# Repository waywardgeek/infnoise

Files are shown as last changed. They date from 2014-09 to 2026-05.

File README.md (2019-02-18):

### Infinite Noise TRNG (True Random Number Generator)

For instructions for compiling the and using Infinite Noise TRNG driver, go to the software
sub-directory, and read the [README](software/README.md) file there.  Both Linux and Windows
are supported.

The Infinite Noise TRNG is a USB key hardware true random number generator.  It uses what
I call a "Modular Entropy Multiplier" architecture (previously Infinite Noise Multiplier or
FireBug).  Besides being simple, low-cost, and fast, it is much easier to get right than
other TRNGs.  It naturally defends against influence from outside signals, such as radio
interference and power supply noise, making it simple to build securely, without requiring
an expert in analog design.  Modular entropy multipliers produce a provable and easily
measured level of entropy based on thermal noise, approximately equal to log2(K) per
output bit, where K is a gain between 1 and 2 set by two resistors around an op-amp.  A
"health monitor" can track this and verify that the output entropy is within the expected
range, which for the Infinite Noise TRNG described below is within 2% of log2(1.82).

Modular entropy multipliers are suitable for both board level implementation and ASIC
implementation.  Speed is limited by the speed of a gain stage and a comparator, and can
run in excess of 100 Mbit/second per second with high performance components.  Cheap
solutions with CMOS quad op-amps can run at 8Mbit/second.

Adjacent bits from a modular entropy multiplier are correlated, so whitening is required
before use in cryptography.  This should be done by continually reseeding a
cryptographically secure hash function such as SHA-512, Blake2b, Keccak-1600 (SHA3), or a
stream cipher such as ChaCha.  This implementation uses Keccak-1600 with cryptographically
secure reseeding of more than 400 bits of entropy at a time, overcoming a trickle in/out
problem present in the GNU/Linux /dev/random system.  Users who need many megabytes per second
of data for use in cryptography can set the outputMultiplier as high as they like, which
causes Keccak to generate outputMultiplier\*256 bits per reseeding by the Infinite Noise
TRNG.

The modular entropy multiplier architecture was invented by Peter Allan in 1999, which he
called [Firebug](http://apa.hopto.org/firebug).  I reinvented it in 2013.  As usual, most
of my good ideas are rediscoveries of existing ideas :-)  Peter has his own
version called [the Redoubler](https://github.com/alwynallan/redoubler), which
is awesome.  It really is the _right_ way to generate random bits, whether on a
board with standard parts, or on an custom chip.

### Crowd Supply campaign

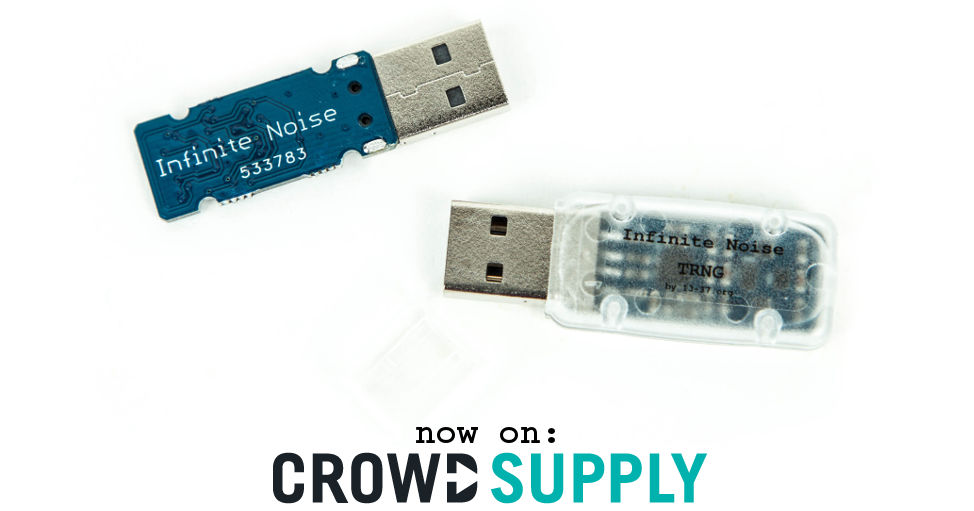
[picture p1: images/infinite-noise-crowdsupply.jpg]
Infinite Noise Crowd Supply campaign Infinite Noise Crowdsupply campaign.


With the aid of crowdfunding, the Infinite Noise will soon be produced (again)! The campaign is driven by Manuel Domke, founder of a fresh electronics manufacturing company called 13-37.org electronics. 

[Check the Crowd Supply project page for latest updates](https://www.crowdsupply.com/13-37/infinite-noise-trng)

### The Eagle open-source boards work!

Here is the first completed Infinite Noise USB key.  I offered this model on
Tindie to help get the modular entropy multiplier concept out there initially.

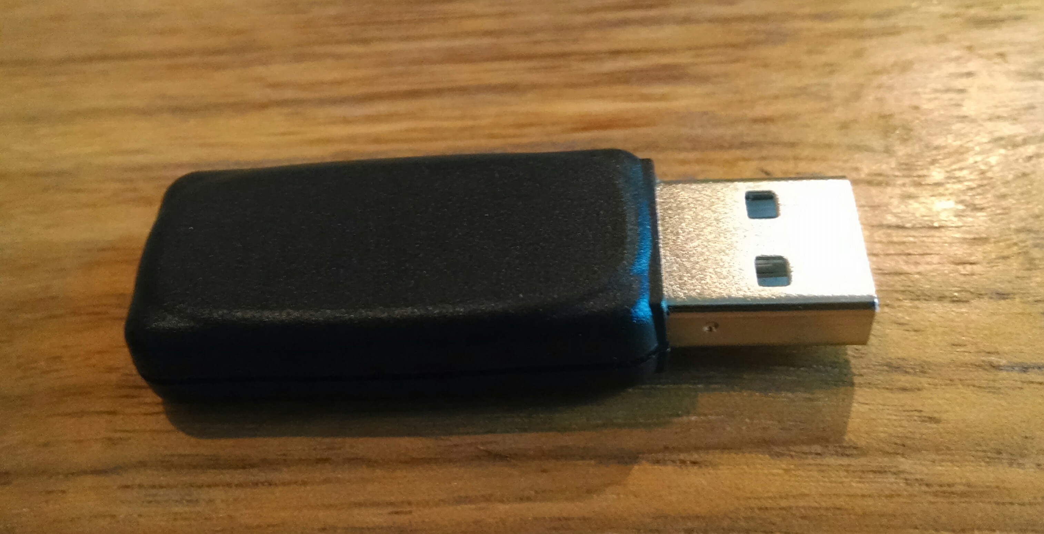
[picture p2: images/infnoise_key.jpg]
Picture of Infinite Noise USB key Infinite Noise USB key


Here are the first three boards from OSH Park.  They work _exactly_ as predicted.  They all
generate 300,000 bits per second, resulting in a measured 259,000 bits of entropy per second, which is within 0.5% of the predicted value of log2(1.82).

All three boards should produce log2(1.82) = 0.864 bits of entropy per bit by design.  The first one is estimated
to produce 0.867, while the second one produces 0.868, and the third is 0.867.

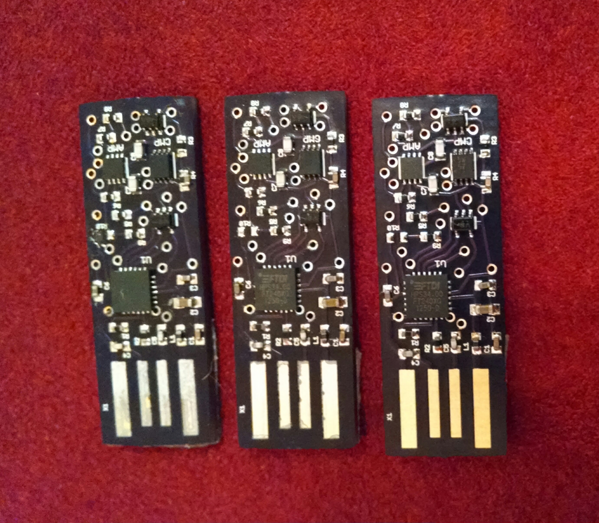
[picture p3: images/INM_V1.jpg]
Picture of Infinite Noise Multiplier circuit board Infinite Noise Multiplier


Here is the latest schematic:

![Schematic of Infinite Noise Multiplier](images/infnoise.png?raw=true "Infinite
Noise Multiplier")

Here is the latest board layout (thanks, EagleWorks!):

![Board layout of Infinite Noise Multiplier](images/infnoise_brd.png?raw=true "Infinite
Noise Multiplier")

The breadboard worked, too.  Estimated entropy per bit is 0.81 for the bread-board.  By design, it should
be 0.80, so it is very close to the prediction.  The breadboard proved out much of the theory of operation, as well os providing raw data for entropy testing.

![Breadboard of Infinite Noise Multiplier](images/infnoise_breadboard.jpg?raw=true "Infinite
Noise Multiplier")

Here is the voltage on one of the hold cap:

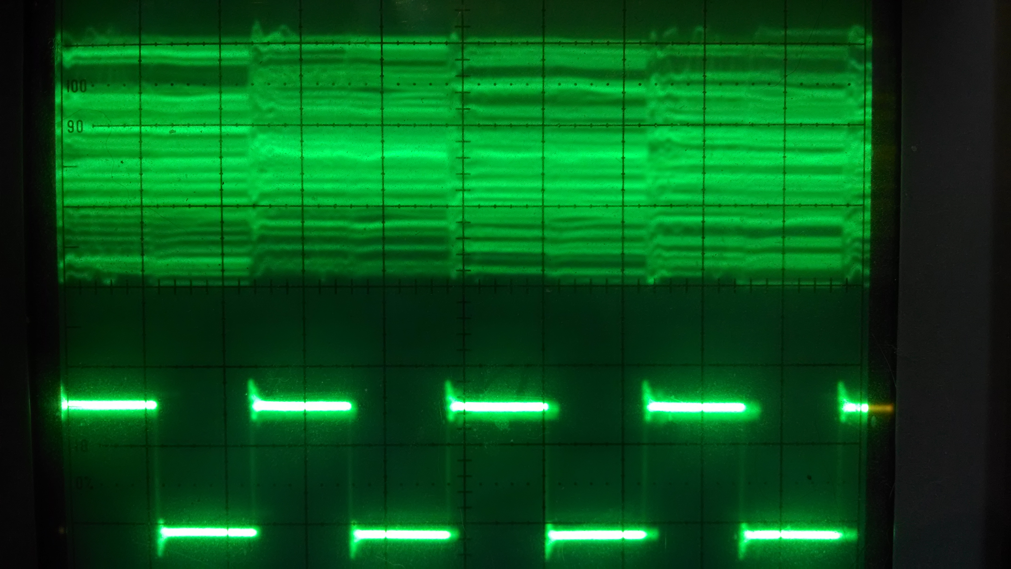
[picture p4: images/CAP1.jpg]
Traces on left hold cap


To build one of these for yourself, you can [order three boards from OSH Park for only
$3.25](https://oshpark.com/profiles/WaywardGeek), and then buy parts from [Digikey and
Mouser as described in the
BOM](https://github.com/waywardgeek/infnoise/blob/master/eagle/BOM.xlsx?raw=true).  I
designed this board to be cheap, not easy to assemble by hand.  I use 2 QFN parts and
three with 0.5mm lead pitch.  If you want to [build these yourself the way I
do](https://www.sparkfun.com/tutorials/59), consider uploading the [infnoise.brd
file](https://raw.githubusercontent.com/waywardgeek/infnoise/master/eagle/infnoise.brd) to
[OSH Stencils](https://www.oshstencils.com/) and ordering a solder paste stencil for $7.
I get the [solder paste from SparkFun](https://www.sparkfun.com/products/12878).  Kudos to
OSH Park, OSH Stencil, SmallBatchAssembly, and DigiSpark!  They're making this whole party
possible!

The total for all the parts, including boards from OSH Park, come to $5.69 each, in 1,000
unit quantities.  However, that cost is dominated by USB related parts, particularly the
FT240X chip, the USB connector, and the USB-stick enclosure.  Just the components for the
modular entropy multiplier come out to $0.97.

Cor van Wandelen was kind enough to create these scatter plots showing the non-randomness
in the raw output.
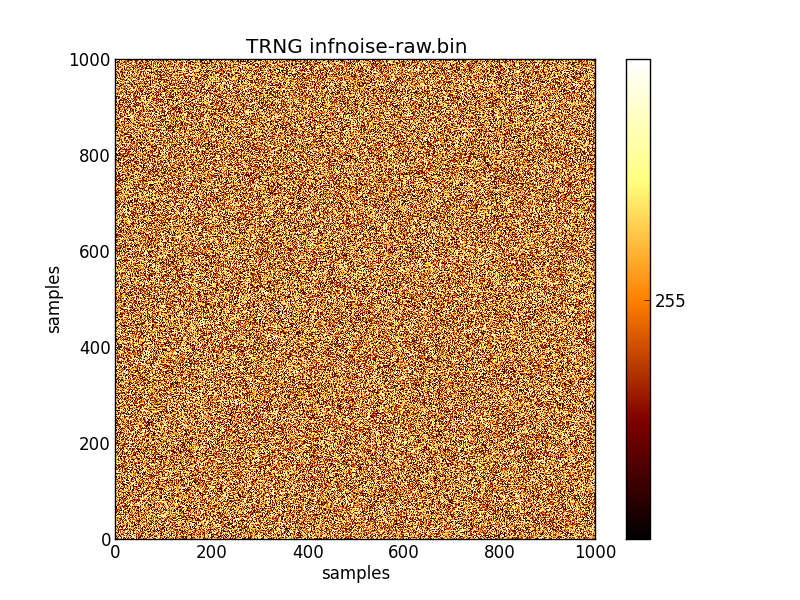
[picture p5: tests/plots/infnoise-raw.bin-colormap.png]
color plot of raw data Color plot

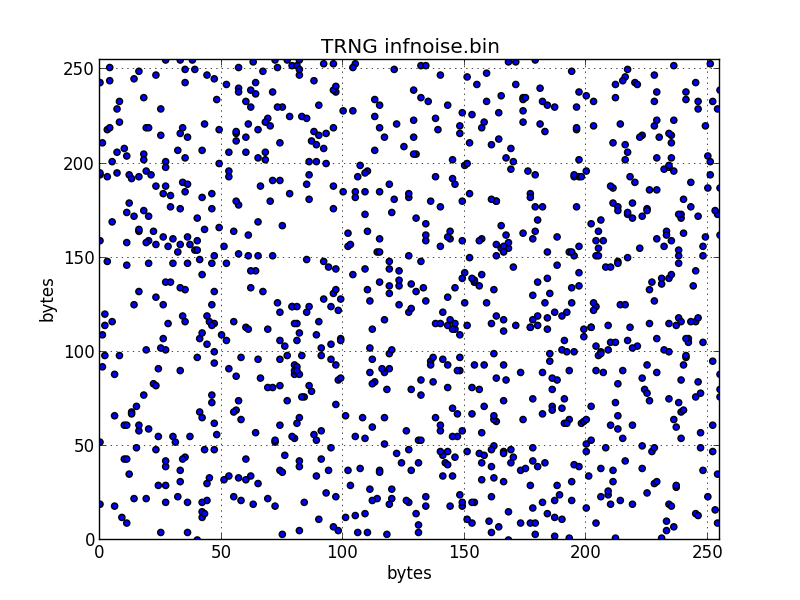
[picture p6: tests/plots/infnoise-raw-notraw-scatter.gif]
scatter plot of raw data Scatter plot


Here is a faster version that uses a more expensive op-amp from TI:

![Schematic of Infinite Noise Multiplier](infnoise_small/schematic.png?raw=true "Infinite
Noise Multiplier")

### The Problem: Noise Sensitivity, and Signal Injection

True random number generators are very difficult to get right.  Generally, they amplify a
tiny noise signal, perhaps only a microvolt in amplitude, by a factor of millions or
billions, until the signal is an unpredictable digital signal.  This signal is then
sampled to see if it's a 0 or 1.

The problem with this approach is the weak noise source can easily be influenced by other
nearby signals, which may be under the control of an attacker, or perhaps observable by an
attacker, enabling him to predict the output.  Systems built with massive amplification of tiny noise sources often require power supply filters and EMI shielding, and even then remain difficult to prove secure.  Generally, an expert analog designer is needed to get it right.

Intel's RDRAND instruction is a perfect example.  It uses rapid amplification of thermal
noise to determine the power-up state of a latch.  Unfortunately, this source of entropy
is highly power-supply and cross-talk sensitive.  Intel claims to have
carefully shielded their thermal noise source, but without a thorough pubic audit of both
the design and layout, including all potential sources of interference, it is not possible
to trust the RDRAND instruction as the source of entropy for cryptography.

With such strong sensitivity, these TRNG architectures are potential targets for signal
injection by an attacker, who can cause the TRNG to generate his desired output rather
than true random data.

### The Solution: Modular Multiplication

Unpredictable noise sources are tiny, and must be massively amplified to be used by an
TRNG.  Other TRNG architectures amplify these signals until they saturate, becoming
digital 1's and 0's.  They rely on careful design and shielding to keep outside signals
from influencing the noise source.

For example, if we amplify a tiny noise source by 1 billion in a system that saturates at
3.3V, then 1uV of noise will be amplified causing the output to be about 3.3V.  An
attacker need only introduce at least -1uV to cause the TRNG to saturate at 0V instead.
An attacker with even this tiny influence can entirely control the output.

If TRNGs used modular multiplication to amplify their noise source, this noise sensitivity
problem would go away.

If we multiply a 1uV peak by 1 billion modulo 3.3V, then the result will be about 0.3V,
which will result in a digital 0.  If an attacker subtracts 1uV, causing our noise source
to be at 0.0V, then after amplification, the output is 0V, which still results in a 0.  In
fact, without knowing the current amplitude of the noise source, there is no signal an
attacker can add to our noise source to control the output.  He may be able to flip the
output bit, but since it was already random, his signal injection fails to control the
result, which is still random.  In fact, an attacker's injected signal causes the output
to be _more_ random, since an attacker is a nice unpredictable source of entropy!
Infinite Noise Multipliers _add_ entropy from all noise sources, even those from an
attacker.

### Variations

There are currently 3 versions of Infinite Noise Multipliers documented here.  The
infnoise_small directory describes a low part-count design that works well with op-amps
which have rail-to-rail inputs and outputs.  It runs at 4MHz, outputting 0.86 bits worth of
entropy on each clock (loop gain = 1.82), for a total of over 3.4 Mbit of entropy produced
per second.  The infnoise_fast directory contains a 50% faster design that uses a few more
resistors and an additional op-amp.  This design is suitable for use with a wide range of
op-amps.  It runs at 6MHz, outputting 0.86 bits worth of entropy on each clock (loop gain =
1.82), for over 5Mbit of entropy per second.

Because Infinite Noise Mulitpliers are switched-capacitor circuits, it is important to use
components with low leakage, like the OPA4354 CMOS quad op-amp from TI.  Op-amps with
below 1nA of input bias current will enable running at lower frequencies with less power.

To reproduce these simulations, download the TINA spice simulator from Ti.com.

Here is a "small" modular entropy multiplier:

![Schematic of small Infinite Noise Multiplier](infnoise_small/schematic.png?raw=true "Small
Infinite Noise Multiplier")

Note that the upper left op-amp is used as a comparator, and must settle to either 0V or
Vsup before the lower left op-amp can multiply the input by 2X.

Here's a "fast" version that does two multiplications in parallel and uses the comparator
result to select the right one.

![Schematic of fast Infinite Noise Multiplier](infnoise_fast/schematic.png?raw=true "Small
Infinite Noise Multiplier")

There is also a [CMOS version described here](http://waywardgeek.net/RNG).

### Simulations

LTspice was used to simulate the small and fast variations.  Here are simulation waveforms
for the small version:

![Simulation of small Infinite Noise Multiplier](infnoise_small/shortsim.png?raw=true "Small
Infinite Noise Multiplier")
![Simulation of small Infinite Noise Multiplier](infnoise_small/longsim.png?raw=true "Small
Infinite Noise Multiplier")

And again for the fast version.

![Simulation of fast Infinite Noise Multiplier](infnoise_fast/shortsim.png?raw=true "Fast
Infinite Noise Multiplier")
![Simulation of fast Infinite Noise Multiplier](infnoise_fast/longsim.png?raw=true "Fast
Infinite Noise Multiplier")

### Theory of Operation

Consider how a successive-approximation A/D converter works.  Each clock cycle, we compare
the input voltage to the output of a D/A converter, and if it's higher, the next bit out
is 1, and if lower, it's a 0.  We use binary search to zero-in on the analog input value.
Here is a block diagram from Wikipedia:

![Successive approximation A/D block diagram](images/SA_ADC_block_diagram.png?raw=true "SAR
A/D Block Diagram")

There is another way to build a successive-approximation A/D that eliminates the D/A
converter.  Compare the input to Vref (1/2 supply), and if it is larger, subtract Vref
from the input.  Then multiply by 2X.  The bit out is the value of the comparator.

    Vin' = Vin >= Vref? Vin - Vref : Vin

This eliminates the D/A converter, and has no limit on how many bits we shift out.  In
reality, the only reason we do not use this architecture for real A/D converters is that
it's accuracy depends on the accuracy of the multiply by 2X operation.  A simple circuit
with 1% resistors would only achieve about a 7 bit resolution.

However, just because the bits are not accurate does not mean we can't keep shifting them
out.  What are we measuring after shifting 30 times?  It's just noise in the circuit, with
no correlation to the original Vin.  It's totally random unpredictable nonsense.  This is
the idea behind the Infinite Noise Multiplier.

If this A/D converter was perfect, both 0's and 1's should shift out with equal
probability, with no correlation between bits.  This has been verified C simulations and
dieharder.  However, due to accuracy limitations on real components, we cannot multiply by
exactly 2X every cycle.  When the loop amplification is < 2X, the entropy per output bit
is reduced, but can be easily computed.  If E is the entropy per bit, and K is the loop
amplification, then:

    E = log(K)/log(2)

or equivalently:

    E = log2(K)

This provides a simple way to calculate the entropy added to an entropy pool per bit.
The program infnoise.c directly measures the entropy of modular entropy multiplier output,
and compares this to the estimated value.  Both simulations and actual hardware show that
they correlate well.

The "fast" board level version uses two op-amps and comparator to impliment a modular
multiplication using a couple of tricks.  First, multiplication by 2 modulo Vsup is
accomplished by multiplying relative to either GND or Vsup.  When multiplying relative to
GND, a 0.2V signal becomes 0.4V.  When multiplying relative to a 3V Vsup, a 2.8V signal
becomes 2.6V, because 2.8V is 0.2V below 3V, and after 2X, it's 0.4V below 3V.  The math
comes out the same as if I'd multiplied relative to GND, and simply subtracted Vsup if the
result was > Vsup:

    Vsup - 2*(Vsup - Vin) = Vsup - 2*Vsup + 2*Vin = 2*Vin - Vsup
        = 2*Vin mod Vsup

So, we multiply by 2 either way, and only subtract out Vsup if needed.  This is identical
to multiplication modulo Vsup.  The comparator simply selects the output of one of the two
op-amps.  This is the basic analog modular multiplier.

A second trick used to create the "small" version was to notice that the output of the
comparator could be used to combine both multiplier op-amps into 1.  This abuse of the
comparator output needs to be carefully checked.  In particular, the output is generally
treated as a digital signal, but in this case, it is used as an analog singal.  Care
should be taken not to load the OUT signal significantly.

### Provable Entropy, Based on Thermal Noise

The RMS thermal noise generated by a resistor of value R is:

    Vnoise = sqrt(4*Kb*T*deltaF*R)

where Kb is Boltzmann's constant 1.3806504×10-23 J/K, T is temperature in Kelvin (about
293 for room temperature), and deltaF is the frequency range of noise being measured.

For the V1 version of the Infinite Noise boards above, the op-amp has an 8MHz unit gain
crossover, and a low load negative input with 10K Ohms in parallel with 8.2K Ohms, which
is 4.5K Ohms.  Vnoise up to unity crossover is about 24uV, and gets amplified by the
op-amp gain K of 1.82 to about 40uV, and held on a 220pF capacitor.  A 40uV change on the
hold capacitors results in a current of about 55,000 electrons, so the hold capacitors are
able to capture about 15 bits of resolution of this noise signal, which gets amplified by
K and combined with later noise samples in the hold capacitors every cycle.  The
capacitors s hold about 2^31 different charge levels in the range of 0.3V to 3V.  This is
effectively a 31-bit register which we multiply by 1.82 every cycle and add a 15 bit noise
signal.  This results in entropy shifted out just slightly less than log2(1.82), since
this entropy compression does not result in 100% pure entropy (just very close).

changes the output of the comparator several cycles later.  Each cycle, this 15-bit noise
signal is added in, far in excess of the log2(K) of entropy we shift out, enabling us to
concentrate entropy in the hold capacitors, which hold over 2^32 electrons when
discharging from the design range of 3V to 0.3V.  Note that we are not assuming successive
noise samples of this 8MHz noise, when measured at 480KHz, will be completely uncorrelated,
but only that concentrating a 15-bit representation of sequential samples will have a few
bits of "surprise", which is log2(1/probability of guessing the next sample).

### Analysis of Analog Modular Multiplication

Consider a traditional zener TRNG:

    Vzener -> Multiply by 1e9 relative to Vref -> Clamp between -Vsupply and Vsupply -> digital 0/1

For simplicity, assume our amplifier has positive and negative supplies, Vsupply, and
-Vsupply.  If Vzener\*1e9 >= 0, then the output is a digital 1, otherwize 0.

There are variations on this theme, but this is basically how Zener TRNGs work.  The math
computed by this circuit is:

    clamp(-Vsupply, Vsupply, 1e9*Vzener)

where the first two parameters are the lower and upper clamping voltages, and the third
parameter is the amplified signal.

The problem with this design is that an attacker, Malory, can override the tiny zener
noise source with radio-signals, or any of a number of attacks.  Basically, if he can find
a way to add his signal to Vzener, then the circuit does this:

    clamp(-Vsupply, Vsupply, 1e9*(Vzener + Vmallory))

If Vmallory is always just a bit larger than Vzener in magnitude, then Mallory can
completely determine the output, because Mallory can make Vzener + Vmallory greater or
less than zero at will, and after multiplying by 1e9 it the amplifier will saturate in the
direction of the sign of Vmallory.

What if we used modular multiplication instead?  Assume we represent Vzener now as a
positive voltage between 0 and Vsupply so we can use the normal mod operation.  In this
case the normal output would be:

    Vzener*1e9 mod Vsupply -> compare to Vsupply/2 -> 1 if > Vsupply/2, 0 otherwise

This is even _more_ unpredictable than the original version. Only the portion of Vzener
between +/- Vsupply/1e9 made any difference in the output before, but now we use the
entire amplitude of Vzener.  The amplitude of Vzener has additional entropy which now
further whitens the output bit.

When Mallory attacks this system, injecting Vmallory into the same node as Vzener, it
computes:

    (Vzener + Vmallory)*1e9 mod Vsupply = Vzener*1e9 + Vmallory*1e9 mod Vsupply

Let Vz = Vzenner\*1e9 mod Vsupply, and Vm = Vmallory\*1e9 mod Vsupply.  Then the output
is just:

    Vz + Vm mod Vsupply

Vz is unpredictably distributed between 0 and Vsupply, hopefully somewhat uniformly.
How can Mallory determine what to add to it to control the output?  He can not.
His interference can only _increase_ the entropy of the output, since Mallory's attack is
itself an entropy source, further randomizing the result.

### Rolling Up the Loop

A 30-long cascade of switched capacitor 2X modular multipliers is a lot of hardware!
Fortunately, it is possible to reuse the same multiplier for each stage, without even
slowing down the circuit.  In our long chain of 2X modular multipliers, we computed:

    A1(1) = 2*Vzener(0) mod Vsupply
    A2(2) = 2*A1(1) mod Vsupply
    A3(3) = 2*A2(2) mod Vsupply
    ...
    A30(30) = 2*V29(29) mod Vsupply

Here, Vzener(0) is Vzener when sampled at the first clock pulse.  Vzener(n) is the voltage
sampled on the nth clock pulse.  An(i) is the output of the nth 2X modular multiplier at
clock cycle i.  Instead of using 30 stages, what would happen if we simply fed the output
of the 2X modular multiplier stage back on itself?  We'd just have A instead of A1 ..
A30:

    A(1) = 2*Vzener(0) mod Vsupply
    A(2) = 2*(Vzener(1) + A(1) mod Vsupply 
          = 2*Vzener(1) + 4*Vzener(0) mod Vsupply
    A(3) = 2*(Vzener(2) + A(2)) mod Vsupply
          = 2*Vzener(2) + 4*Vzener(1) + 8*Vzener(0) mod Vsupply
    ...
    A(30) = 2*Vzener(29) + 4*Vzener(28) + 8*Vzener(27) + ... + 2^30*Vzener(0) mod
    Vsupply

If 2^30\*Vzener(0) mod Vsupply is an unpredictable value, then the other terms can in no
way reduce this unpredicability.  What if Mallory attacks?  In that case, at step 30, we
have:

    A(30) = 2*(Vzener(29) + Vmallory(29)) + ... + 2^30*(Vzener(0) + Vmallory(0) mod
    Vsupply
            = [2*Vzener(29) + 4*Vzener(28) + ... + 2^30*Vzener(0)] +
              [2*Vmallory(29) + 4Vmallory(28) + ... + 2^30*Vmallory(0)] mod Vsupply

The output is just the signal we had before without Mallory's influence, plus a value
injected by Mallory, mod Vsupply.  Once again if Mallory does not know what the value of
A(30) would have been, he cannot control the result.  He can only make it more random.

The value of A acts as an entropy pool, collecting entropy from all signals that impact
it's value.

### We Don't Need Zener Noise

In reality, there are many sources of unpredictable noise in every circuit.  There's large
predictable and controllable noise, like power supply noise, and tiny 1/f noise in the
multi-gigahertz range.  Shot noise, thermal noise, EMI, cross-talk... you name it, no
matter where we look, there's noise.  Infinite noise multipliers amplify them all in
parallel, and adds them together effectively in an tiny entropy pool.  Zener noise would
be just one more source of noise in a symphony of existing noise sources, and will not
enhance the resulting entropy enough to bother.

A modular entropy multiplier will amplify _every_ source of niose and amplify it until it is
larger than Vsupply.  It adds them together and amplifies them in parallel.  Every device
in the signal path loop contributes. 

With N sources of noise, the output looks like:

    V1(1) = Vnoise1(1) + Vnoise2(1) + Vnoise3(1) ... VoinseN(1)
    ...
    V1(30) = [2*Vnoise1(29) + 4*Vnoise1(28) + ... + 2^30*Vnoise1(0)] +
             [2*Vnoise2(29) + 4*Vnoise2(28) + ... + 2^30*Vnoise2(0)] +
             ...
             [2*VnoiseN(29) + 4VnoiseN(28) + ... + 2^30*VnoiseN(0)] mod Vsupply

Each individual noise sources contributes its own power-of-two sequence to the total.
A micro-volt noise source contributes nearly as strongly as a Vsupply/10 amplitude noise
source.

The mashing together of noise source data with unbounded modular multiplications leads to
awesome entropy levels.  Just how awesome?  Consider just thermal noise from one resistive
summing node (the minus terminal on op-amp in the 2X gain stage).

How correlated are successive samples?  How badly does this impact our output?  It turns
out that high correlation is OK.  What we want is high resolution contribution of noise
samples, even more than low correlation.

Suppose sample Vnoise(0) is 1.034 uV, and Vnoise(1) is 1.019 uV.  That is
some bad correlation, but 14 clock cycles later, the difference in amplitudes between
these samples will have the output toggling unpredictably.  What matters is not
correlation between noise samples, but the accuracy to which we can remember the
difference between them in our circuit.  This should be limited only by electron counts on
our hold capacitor.  It has an integer number of electrons at any time.  About 2.5 billion
electrons flow out of 100pF holding caps when charging from 0.5V to 4.5V.  That's about 31
bits of resolution.  Every time we capture noise on these caps, it adds or subtracts an
integer number of electrons.  Each electron contributes about 1.6nV on our hold cap.  So
long as we can capture noise that has significantly more than 1.6nV of unpredictability,
we should be able to keep the output generating close to 1 bit of entropy per clock.  In
this example, both noise samples had over 10X the minimum resolution in unpredictable
noise, and easily contributed a bit of entropy each to our 31-ish bit entropy pool.

### Whitening the Right Way

Data coming from true random number generators is never 100% random.  I am aware of no
exceptions.  Whitening is required in all cases before the data is suitable for use in
cryptography.

Most TRNGs build whitening into the hardware.  This is a _mistake_, at least if the
whitening cannot be turned off.  Respectable TRNGs, such as [OneRNG](http://onerng.info/)
and [Entropy Key](http://www.entropykey.co.uk/) provide hardware whitening, but also
provide access to the raw data streams for health analysis.

I prefer to follow the KISS rule when it comes to security.  The more complex the TRNG
key, the more likely it is insecure.  Therefore, the initial Infinite Noise Multiplier
does not even have a microcontroller onboard, and only returns raw data, direct from the
noise source.  Whitening is done in the Infinite Noise driver.

The Infinite Noise driver uses the reference version of the SHA3 "sponge", called Keccak,
with a 1600 bit state.  To make the state of the sponge unpredictable, it is initialized
with 20,000 bits of of Infinite Noise data before any data is output.  After that, reading
bytes from the SHA3 sponge blocks until twice as many bytes of entropy have been fed into
the sponge from the Infinite Noise TRNG.

### Non-Power-of-Two Multiplication

The circuit shown in infnoise_fast multiplies by 1.82 every clock rather than 2.0.  As
stated above, this reduces the entropy per output bit to log(1.82)/log(2) = 0.86 bits of
entropy per output bit.

Suppose in cycle 0, the noise Vnoise(0) is +/- Vsupply/2^30V every cycle.  At most 31 clock
cycles can go by before the output toggles due to Vnoise(0), because on cycle 31, it's
contribution will be 2\*Vsupply, and the remaining noise contributions can do no more than
subtract Vsupply.  This will have to be subtracted out.  The cycle x1 where we know
Vnoise(0) will have toggled the output is:

    Vnoise(0)*2^x1 >= 2*Vsupply
    2^x1 >= 2*Vsupply/Vnoise(0)
    x1 >= log(2*Vsupply/Vnoise(0))/log(2)

When multiplying by K, where 1 < K < 2, it takes more clock cycles for Vnoise(0) to reach
Vsupply, insuring that it will have changed the output.  The cycle x2 when this happens
is:

    Vnoise(0)*K^x2 >= 2*Vsupply
    K^x2 >= 2*Vsupply/Vnoise(0)
    x2 >= log(2*Vsupply/Vnoise(0))/log(K)

The ratio of the clocks it takes with amplification 2 vs K is:

    x1/x2 = [log(Vsupply/Vnoise(0))/log(2)] / [log(Vsupply/Vnoise(0))/log(K)]
          = log(K)/log(2)

It takes log(2)/log(K) more cycles to insure the output is different.
the entropy shifted out with exactly 2X amplification will be 1 bit per clock.

### Health Monitoring

Infinite Noise Multipliers output entropy at a predictable rate, which is measured
continually.  If the entropy per bit deviates from the theoretical value of log(K)/log(2)
by more than 2% during the previous 80,000 bits, then the driver stops generating output.
Some deviation is expected, since K is dependent on two resistor values, which can be off
by 1% each.  Also, a significant amplitude noise in the system, as well as "misfires", can
cause more entropy to be output than predicted.  The estimated entropy per bit are
continually estimated and compared to expected values.

Entropy per bit is measured as the log2 of one over the probability of seeing a specific
output sequence from the modular entropy multiplier.  The probability of any given output
bit is estimated by keeping a history of results, given the previous 7 bits.  Simulations
with K=1.82 show that using 16 bits rather than 7 gives only a 0.16% improvement in
prediction accuracy, so only 7 are used.

### Entropy Testing

A common program used to estimate entropy in a data stream is "ent".  A sample data file
was created this way (using one of the original V1 boards):

    $ sudo ./infnoise-v1 --raw --debug > foo
    ...
    Generated 14680064 bits.  OK to use data.  Estimated entropy per bit: 0.866710, estimated
    K: 1.823500
    num1s:49.888504%, even misfires:0.159748%, odd misfires:0.127300%
    Generated 15728640 bits.  OK to use data.  Estimated entropy per bit: 0.866856, estimated
    K: 1.823684
    num1s:49.901504%, even misfires:0.145973%, odd misfires:0.160365%
    Generated 16777216 bits.  OK to use data.  Estimated entropy per bit: 0.867010, estimated
    K: 1.823879
    num1s:49.963040%, even misfires:0.146815%, odd misfires:0.145067%

Here's ent's results on the raw data stream this run produced:

    $ ent foo
    Entropy = 7.318058 bits per byte.
    
    Optimum compression would reduce the size
    of this 2072576 byte file by 8 percent.
    
    Chi square distribution for 2072576 samples is 1510131.51, and randomly
    would exceed this value 0.01 percent of the times.
    
    Arithmetic mean value of data bytes is 127.5088 (127.5 = random).
    Monte Carlo value for Pi is 3.427100794 (error 9.09 percent).
    Serial correlation coefficient is -0.005035 (totally uncorrelated = 0.0).

The health monitor does a much better job at estimating the entropy than ent.  The actual
non-randomness is 60% higher than ent predicted.  Ent said 0.915 bits of entropy per bit,
while the health monitor measured 0.867.  The health monitor's entropy estimator is just a
tiny fraction of a percent higher than the model predicts, while ent is off by 4.8% .  The
design target for entropy per bit was log2(1.82) = log(1.82)/log(2) = 0.864.  This is set
by two resistors.  Based on entropy measured by the health monitor, it could compress this
file by 13.3%.

The entropy estimator is based on the model that:

- The device is not rapidly changing the sort of numbers it puts out, so history can be
  used as a guide.
- There is no special state stored in the modular entropy multiplier that could cause data
  to be different each clock cycle, other than on even/odd cycles.
- Bits further away are less correlated.

The first assumption is strong assuming an attacker is not involved.  An attacker
injecting a strong signal could mount a DoS attack, since the health monitor would detect
entropy being too high, and would disable output.  This is a conscious choice: the health
monitor could instead simply warn that entropy seems too high.  Turning off the output
when an attacker may be present seems the safer choice.

The second assumption relies on the fact that only two nodes store state in this
implementation of a modular entropy multiplier, and that the outputs are sampled from
even/odd comparator outputs on even/odd cycles.  Other TRNGs may not satisfy this
assumption if they have additional internal state.  However, a typical zener TRNG should
satisfy this assumption.

The third assumption really does require a modular entropy multiplier.  A zener TRNG would
most likely have strong 60 Hz correlations from 60 Hz noise, for example.  This is also
true of A/D converter based TRNGs.  With a modular entropy multipliers, these signal sources
are added to a signal already saturated with thermal noise, making it in no less random.
Every cycle, a new thermal noise sample is added to the state, causing less correlation
with previous states.

### Future Version

I'm really just having fun with this project.  I personally prefer this version

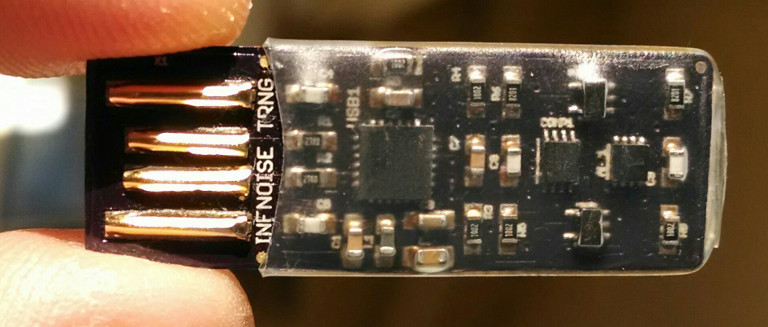
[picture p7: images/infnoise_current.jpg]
Infnoise TRNG I carry The TRNG I carry around


I plan on only making this version going forward, even though I doubt it will sell very
well.  That's OK, because I don't make any money on them :-)

### Credits

Peter Allan has been very helpful in moving this project forward.  The github user known
as EagleWorks did an _amazing_ job redoing the board layout.  Somehow, my ameraturish work
just wasn't good enough for him :-)  Thanks, EagleWorks!  Cor van Wandelen created the
color and scatter plots.

### Free As in Freedom

The modular entropy multiplier architecture was invented in 1999 by Peter Allan, but was not
patented at that time.  Peter is working with me to make modular entropy multiplier/Firebug
open-source hardware, unencumbered by patents or copyright.

I reinvented with the modular entropy multiplier architecture in 2013, and the board level
versions in 2014.  I hereby renounce any claim to copyright and patent rights related to
any changes or improvements I may have made to this architecture.  Furthermore, I am aware
of no infringing patents and believe there are none.  It should be entirely safe for use
in any application.  Feel free to copy anything here, and even sell your own modular
noise multiplier based USB keys based on this work.

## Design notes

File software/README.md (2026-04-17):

Releases
---------------------------------

Signed packages of release versions are availabe on [Github](https://github.com/leetronics/infnoise/releases) and [13-37.org](https://13-37.org/files/).

The packages are signed with the same PGP-Key (Key-ID: `0x4E730A3C`) used for the apt repositories below. 
Full Fingerprint: `71AE 099B 262D C0B4 93E6 EE71 975D C25C 4E73 0A3C`. You can get the keys on [13-37.org/keys](https://13-37.org/keys) and in the [Crowd Supply campaign](https://crowdsupply.com/13-37/infinite-noise-trng).

Verify the keys and add the repo:

    $ wget -O 13-37.org-code.asc https://13-37.org/files/pubkey.gpg 

    # Verify the keys fingerprint:
    # GPG1
    $ gpg --with-fingerprints 13-37.org-code.asc
    # GPG2:
    $ gpg2 --import-options import-show --dry-run --import < 13-37.org-code.asc

    $ sudo apt-key add 13-37.org-code.asc

    $ echo "deb http://repo.13-37.org/ stable main" | sudo tee /etc/apt/sources.list.d/infnoise.list
    $ sudo apt-get update
    $ sudo apt-get install infnoise

Connect the Infinite Noise TRNG (if not already) and the service will be started via a udev rule. Check status of driver: 

    $ systemctl status infnoise

Compiling the Driver 
------------------------------

It's highly recommended to build from the tagged releases, as these have been [tested and verified](https://github.com/leetronics/infnoise/tree/master/tests/results) extensively. Note that the releases are maintained in the 13-37-org fork of this project.

To switch to a specific tag:
    
    git clone https://github.com/leetronics/infnoise
    git checkout tags/0.3.0

GNU/Linux
------------------------------

The infnoise application reads random data from the Infinite Noise USB key and writes
binary data to stdout.  To compile it, you will need to install the libftdi and libusb
development libraries to compile infnoise.  In Ubuntu (probably also Debian), you can use
this command:

    $ sudo apt-get install libftdi-dev libusb-dev

These include an open source drivers for the FT240X USB chip used on the Infinite Noise
TRNG.  Once this is done, to compile the infnoise program, simply make and install it:

    $ make -f Makefile.linux

To install it, run:
    
    $ make -f Makefile.linux install

This also installs a systemd service and the udev rules described below to start the driver automatically when the device is plugged in.

To run the infnoise application manually, make sure the systemd service is stopped. Otherwise it will restart the daemon and disrupt you.

    $ sudo ./infnoise > randbytes

The Infinite Noise USB driver uses the open source FTDI driver documented at:

    http://www.intra2net.com/en/developer/libftdi/documentation/group__libftdi.html

Note that there is a newer alpha version of the next release of the libftdi library.  I
found it runs much slower than the current libftdi1 library in Ubuntu, so I am sticking
with the stable release for now.

MacOS
------------------------------

First install the dependencies, most easily done with homebrew:

    $ brew install libftdi libusb

Adjust the Makefile, if necessary, to point at your ftdi directory:

    $ mdfind -name ftdi.h
    /usr/local/Cellar/libftdi/1.4/include/libftdi1/ftdi.h

then, in your Makefile.macos:
```
FTDILOC = /usr/local/Cellar/libftdi/1.4/include/libftdi1/
```

Next build the executable:

    $ make -f Makefile.macos

If running it fails, you may have to run as root:

    $ sudo ./infnoise

Or you may have to unload the FTDI serial port driver:

    $ sudo kextunload -b com.FTDI.driver.FTDIUSBSerialDriver

Alternatively, FTDI have released the [D2XXhelper](http://www.ftdichip.com/Drivers/D2XX.htm), which may prevent the
serial driver from grabbing the Infinitenoise device.

The `--dev-random` mode is not implemented for MacOS (yet.) 
But you can try the the Infinite Noise [OpenSSL engine](https://github.com/tinskip/infnoise-openssl) based on libinfnoise.

Windows
-----

I compiled infnoise-win.exe using VisualStudio 2013 using Windows 7. I downloaded the FTD2xx drivers from FTDI. Pipes seem almost entirely broken in Windows, so the Windows version requires out output file to be specified on the command line. In a cmd window, you can type

    infnoise-win foo

and let it run for a while until you have as much random data in foo as you need.

The VisualStudio project for infnoise is in the infnoise/software/VisualStudio directory.

There is also a new fork https://github.com/jj1bdx/infnoise-windows compiled with VS2017.

Usage
-----

    Usage: infnoise [options]
    Options are:
        -D, --debug - turn on some debug output
        -R, --dev-random - write entropy to /dev/random instead of stdout
        -r, --raw - do not whiten the output
        -m, --multiplier <value> - write 256 bits * value for each 512 bits written to
            the Keccak sponge.  Default of 0 means write all the entropy.
        -n, --no-output - do not write random output data
        -p, --pidfile <file> - write process ID to file
        -d, --daemon - run in the background
        -s, --serial <serial> - use specified device
        -l, --list-devices - list available devices
        -v, --version - show version information
        -h, --help - this help output

Note: The options --daemon, --dev-random and --pidfile are only implemented in the GNU/Linux version. 
The windows version is also lacking --list-devices and --serial. 

Examples
--------

This will fill the file randbytes with random data endlessly, so hit Ctrl+C to kill it
after a while.  If all you want to do is verify the output using the dieharder tests, you
can use:

    $ sudo ./infnoise | dieharder -g 200 -a

The program "infnoise" talks to the FT240X USB 2.0 interface chip on the USB stick.  It
uses "bitbang" mode to drive the clock signals of the Infinite Noise Multiplier, and
receives one random bit of output per byte written to the device.  These bits are
collected into bytes, and sent through a "health checker", which verifies that the bits
look basically like INM output, with about the expected level of entropy.

If the measured level of entropy deviates from the theoretical value by more than 2%, then
the infnoise application stops generating outputdata.  If it sees too many 0's or 1's in a
row, it will exit with an error code.

You can see the raw data from the INM for yourself by running

    $ sudo infnoise --raw > randbytes

Kill it after a while, and check it out with with a program like hexdump.  In general,
there should be random 0's and 1's, but rarely more than 3 1's or 0's in a row.  You can
get some good debug info using:

    $ infnoise --debug --no-output
    Generated 1048576 bits.  OK to use data.  Estimated entropy per bit: 0.871889, estimated K: 1.830057
    num1s:49.541189%, even misfires:0.137931%, odd misfires:0.137931%
    Generated 2097152 bits.  OK to use data.  Estimated entropy per bit: 0.869644, estimated K: 1.827211
    num1s:49.633114%, even misfires:0.131231%, odd misfires:0.145229%
    Generated 3145728 bits.  OK to use data.  Estimated entropy per bit: 0.867817, estimated K: 1.824899
    num1s:49.556943%, even misfires:0.133887%, odd misfires:0.133887%
    Generated 4194304 bits.  OK to use data.  Estimated entropy per bit: 0.867596, estimated K: 1.824620
    num1s:49.570250%, even misfires:0.160155%, odd misfires:0.144005%
    Generated 5242880 bits.  OK to use data.  Estimated entropy per bit: 0.867907, estimated K: 1.825014
    num1s:49.566724%, even misfires:0.125936%, odd misfires:0.130600%

This prints some basic stats after every 2^20 (about 1 million) bits generated.  They are
run through the health checker which reports "OK to use data" because the measured entropy
is within 2% of the exepcted value.  Estimated K is the gain of the op-amp stage that we
expect to result in the measured level of entropy.  For this design, 1.82 is the design
target, set by a 10K Ohm resistor and an 8.2K Ohm resistor.  Generally, estimated entropy
is slightly higher than the design target due slight deviation from ideal operation.  The
largest source of this non-ideal operation is what I call "misfires", where the output of
the comparator changes in a clock cycle when the inputs are held steady.  The rate of
missfires is reported for even and odd bits, because there is an even and odd comparator
generating bits on alternate cycles, and the two circuits can behave slightly differently.
The number of 1's should ideally be 50%, but due primarily to resistor ratio
imperfections, the actual range is from about 49.5% to 50.5%.

If you need provably random data, which may be comforting in applications such as
one-time-pads, you can compress the bits from the Infinite Noise TRNG 2-to-1 through the
Keccack sponge, cryptographically whitening while reducing the non-randomness to levels
that cannot ever be detected using:

    $ infnoise --multiplier 1 > randbytes

This will take twice as long by default, but every 512 bits are tested to insure they are
not more likely to occur than 1 in 2^433.  With --multiplier 1, only 256 bits are read
from the sponge for each 512 put in.

For most cryptograpy applications, such as generating keys for RSA, we can count on the
cryptographic strength of Keccack-1600 to produce cryptographically undetectably
non-random data when securely seeded with the Infinite Noise TRNG.  The Keccak sponge is
seeded with 512 bits from the Infinite Noise TRNG every time, where the data is tested for
at least 433 bits of estimated entropy.  However, but the amount of data to squeeze from
the sponge is user selectable.  If you want 100MiB/second of Keccak (SHA3) data that is
cryptographically reseeded every 2 megabytes, you can use:

    $ sudo ./infnoise --multiplier 65536 | yourApplication

For even higher seeded CPRNG data rates, bug me and I'll include the "optimized" version
of Keccack, rather than the reference version, or possibly Blake2b which is even faster
than Keccak.

Running as a Deamon
-------------------

Some people need to feed random bits into /dev/random.  This simplest way, and
the way I do it when generating keys, is:

    $ sudo ./infnoise --dev-random --daemon

This tells infnoise to run as a daemon, writing random data to /dev/random.  It
writes 512 bits at once, containing over 400 bits of entropy.  This randomizes
the state all at once.  If the entropy pool is "full" (above the watermark read
from /proc/sys/kernel/random/poolsize), it waits for up to 1 second for it to
fall below the watermark, and after that writes another 512 bits anyway.

This means it runs at full speed when needed, and when not, it randomizes
/dev/random once per second anyway.

Sample init scripts are provided in `software/init_scripts` as a starting point
for setting up system services using this approach.

The other approach people use is rngd.  I had a poor experience with this
program, so I do not use it.  In Ubuntu 14.04, I found that when I told it to
use hardware sources, it also enabled the RDRAND instruction by default, which
is so fast, it never read from any other source!  Rngd also has some minor
issues that are less severe, but these issues in rngd are enough that I shy
away from it.

That said, a lot of people use it, and feel free to follow them.  To do this
you need to create a "named fifo" using the mkfifo command.  Then, you can run
infnoise in the background, writing to the fifo.  Rngd has flags for reading
from a file which will work for this case.  Be careful to also disable RDRAND,
or you will only get Intel's numbers.

Udev rules
----------

This is thanks to user Abigail on github.  If you want to automatically feed
random data into /dev/random when the TRNG is plugged in, you can ask Linux to
do this by creating a file in etc/udev/rules.d. 

It relies on the systemd service "infnoise.service" provided under init_scripts, as udev is not designed to start long-running processes. 

    SUBSYSTEM=="usb", ATTRS{idVendor}=="0403", ATTRS{idProduct}=="6015", ENV{ID_MM_DEVICE_IGNORE}="1", ENV{MTP_NO_PROBE}="1", TAG+="systemd", SYMLINK+="infnoise", GROUP="dialout", MODE="0664"
    ACTION=="add", SUBSYSTEM=="usb", ATTRS{idVendor}=="0403", ATTRS{idProduct}=="6015", ENV{ID_MM_DEVICE_IGNORE}="1", ENV{MTP_NO_PROBE}="1", TAG+="systemd", ENV{SYSTEMD_WANTS}="infnoise.service"

This also adds a symlink so the device removal can also be reacted on.

I personally run the infnoise tool by hand from a bash shell, typically to test devices like this:

     $ sudo ./infnoise --debug --no-output

To avoid having to type 'sudo' each time, I created the following udev rules,
which worked on my particular Ubuntu 14.04 based laptop:

    $ cat 30-infnoise.rules
    SUBSYSTEM=="usb", ATTRS{idProduct}=="6015", ATTRS{idVendor}=="0403", GROUP="dialout", MODE="0664"

Note that my username is in the dialout group.

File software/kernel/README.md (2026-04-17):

# Infinite Noise TRNG Kernel Module

A Linux kernel module for the Infinite Noise TRNG USB device. This driver directly interfaces with the FT240X-based hardware, implements health monitoring, Keccak-1600 whitening, and registers as an hwrng device to feed entropy to the kernel's random subsystem.

## Features

- Hardware random number generator (hwrng) interface at `/dev/hwrng`
- Automatic entropy feeding to kernel CRNG (no rngd required on Linux 3.16+)
- Character device interface at `/dev/infnoiseX`
- Real-time health monitoring with entropy validation
- Keccak-1600 sponge for cryptographic whitening
- Configurable output multiplier for higher throughput
- Hot-plug support
- No conflicts with ftdi_sio driver

## Quick Start

### 1. Reprogram Device VID/PID (One-Time Setup)

The kernel module only recognizes devices with the Infinite Noise VID/PID (`1209:3701`). New devices ship with the default FTDI VID/PID (`0403:6015`) which must be reprogrammed.

See [Device Setup](#device-setup) for detailed instructions.

### 2. Build and Load Module

```bash
# Install prerequisites (Debian/Ubuntu)
sudo apt install linux-headers-$(uname -r) build-essential

# Build
cd software/kernel
make

# Load
sudo insmod infnoise.ko

# Verify
dmesg | grep infnoise
```

### 3. Use

```bash
# Read random data
sudo dd if=/dev/hwrng bs=64 count=10 | xxd
```

## Device Setup

### Why Reprogram?

The Infinite Noise TRNG uses an FTDI FT240X chip which ships with FTDI's default VID/PID (`0403:6015`). This causes conflicts with the kernel's `ftdi_sio` serial driver. By reprogramming to the registered Infinite Noise VID/PID (`1209:3701`), the device is uniquely identified and automatically bound to this driver.

### Prerequisites

```bash
# Debian/Ubuntu
sudo apt install libftdi1-dev ftdi-eeprom

# Fedora
sudo dnf install libftdi-devel ftdi-eeprom

# Arch
sudo pacman -S libftdi
```

### Check Current VID/PID

```bash
lsusb | grep -i "ftdi\|1209"
```

If you see `0403:6015`, the device needs reprogramming. If you see `1209:3701`, it's already configured.

### Program the EEPROM

An `infnoise-eeprom.conf` file is included in this repository.

**Warning:** This permanently modifies the device's EEPROM. Double-check the configuration before proceeding.

```bash
# First, unbind from ftdi_sio if necessary
sudo modprobe -r ftdi_sio

# Read current EEPROM (backup)
sudo ftdi_eeprom --read-eeprom --device i:0x0403:0x6015 backup.eeprom

# Flash new configuration
sudo ftdi_eeprom --flash-eeprom infnoise-eeprom.conf

# Unplug and replug the device
```

### Verify

```bash
# Should now show 1209:3701
lsusb | grep 1209

# Device should show as "Infinite Noise TRNG"
lsusb -d 1209:3701 -v 2>/dev/null | grep -E "idVendor|idProduct|iProduct|iManufacturer"
```

## Building

### Prerequisites

- Linux kernel headers for your running kernel
- GCC and make
- Root access for loading/testing

```bash
# Debian/Ubuntu
sudo apt install linux-headers-$(uname -r) build-essential

# Fedora/RHEL
sudo dnf install kernel-devel gcc make

# Arch Linux
sudo pacman -S linux-headers base-devel
```

### Compile

```bash
cd software/kernel
make
```

## Installation

### Manual Loading

```bash
# Load the module
sudo insmod infnoise.ko

# Verify it loaded
lsmod | grep infnoise
dmesg | grep infnoise
```

### Automatic Loading at Boot

```bash
# Copy module to kernel modules directory
sudo cp infnoise.ko /lib/modules/$(uname -r)/extra/
sudo depmod -a

# Create modprobe configuration
echo "infnoise" | sudo tee /etc/modules-load.d/infnoise.conf

# Optional: set default parameters
echo "options infnoise multiplier=2" | sudo tee /etc/modprobe.d/infnoise.conf
```

### Unloading

```bash
sudo rmmod infnoise
```

## Configuration

### Module Parameters

| Parameter | Type | Default | Description |
|---|---|---|---|
| `debug` | bool | false | Enable verbose debug output |
| `raw_mode` | bool | false | Output raw (unwhitened) data |
| `multiplier` | uint | 1 | Keccak output multiplier (0-10) |

### Setting Parameters at Load Time

```bash
sudo insmod infnoise.ko debug=1 multiplier=4
```

### Changing Parameters at Runtime

```bash
# Enable debug output
echo 1 | sudo tee /sys/module/infnoise/parameters/debug

# Set multiplier to 4x
echo 4 | sudo tee /sys/module/infnoise/parameters/multiplier

# Check current values
cat /sys/module/infnoise/parameters/multiplier
```

### Multiplier Values

The `multiplier` parameter controls how much data is squeezed from the Keccak sponge per entropy absorption:

| Value | Output per Round | Approximate Speed |
|---|---|---|
| 0 | Entropy bits only | ~50 Kbit/s |
| 1 | 32 bytes | ~124 Kbit/s |
| 2 | 64 bytes | ~249 Kbit/s |
| 4 | 128 bytes | ~499 Kbit/s |
| 10 | 320 bytes | ~1.2 Mbit/s |

Higher multiplier values produce more cryptographically secure pseudo-random data per true random sample. The output remains cryptographically secure due to the Keccak sponge construction.

## Usage

### Reading Random Data

```bash
# From hwrng interface
sudo dd if=/dev/hwrng bs=64 count=10 | xxd

# From character device
sudo dd if=/dev/infnoise0 bs=64 count=10 | xxd

# Generate a random file
sudo dd if=/dev/hwrng of=random.bin bs=1M count=10
```

### Checking Device Status

```bash
# View kernel messages
dmesg | grep infnoise

# Check hwrng registration
cat /sys/class/misc/hw_random/rng_available

# Check current hwrng
cat /sys/class/misc/hw_random/rng_current
```

### FIPS 140-2 Testing

```bash
# Install rng-tools if needed
sudo apt install rng-tools  # Debian/Ubuntu

# Run FIPS tests
sudo dd if=/dev/hwrng bs=2500 count=100 | rngtest -c 100
```

### Automatic Entropy Feeding

Since Linux kernel 3.16+, the hwrng subsystem automatically feeds entropy to the kernel's random pool via an internal kernel thread (`hwrng_fillfn`). **No rngd daemon is required.**

The driver dynamically sets the quality parameter based on the output mode:
- **Whitened mode (default)**: quality=990 (Keccak output is cryptographically uniform)
- **Raw mode**: quality=880 (reflects the ~0.88 bits/bit true entropy rate)

The hwrng core thread continuously:
1. Reads data from the device
2. Credits entropy based on the quality setting
3. Mixes it into the kernel's CRNG via `add_hwgenerator_randomness()`

To verify automatic feeding is working:
```bash
# Check hwrng kernel thread exists
ps aux | grep hwrng

# Verify the device is active
cat /sys/class/misc/hw_random/rng_current
```

### Using with rngd (Optional, Legacy)

On older kernels (<3.16) or if you prefer manual control, you can use `rngd`:

```bash
# Install rng-tools
sudo apt install rng-tools

# Start rngd (it will auto-detect /dev/hwrng)
sudo rngd -r /dev/hwrng
```

On modern kernels, this is redundant since the hwrng core already handles entropy feeding.

## Troubleshooting

### Device Not Detected

**Check VID/PID:**
```bash
lsusb | grep -i "ftdi\|1209"
```

If you see `0403:6015`, the device needs to be reprogrammed. See [Device Setup](#device-setup).

**Check module is loaded:**
```bash
lsmod | grep infnoise
```

**Check for errors:**
```bash
dmesg | grep -i "infnoise\|1209:3701"
```

### Warmup Taking Too Long

The device requires approximately 450-500 warmup rounds before producing valid data. If warmup fails:

```bash
# Check dmesg for errors
dmesg | grep -i "infnoise.*failed\|infnoise.*error"

# Try reloading the module
sudo rmmod infnoise
sudo insmod infnoise.ko debug=1
```

### Health Check Failures

Occasional health check failures during warmup are normal. Persistent failures after warmup may indicate a hardware issue:

```bash
# Monitor health status
dmesg -w | grep infnoise
```

### Permission Denied

The device files are owned by root by default. To allow non-root access:

```bash
# Create udev rule for permissions
cat << 'EOF' | sudo tee /etc/udev/rules.d/99-infnoise.rules
# Infinite Noise TRNG - allow user access
SUBSYSTEM=="usb", ATTR{idVendor}=="1209", ATTR{idProduct}=="3701", MODE="0666"
KERNEL=="infnoise*", MODE="0666"
KERNEL=="hwrng", MODE="0666"
EOF

sudo udevadm control --reload-rules
sudo udevadm trigger
```

### Reverting EEPROM Changes

If you need to restore the original FTDI VID/PID:

```bash
# Create restore configuration
cat << 'EOF' > ftdi_restore.conf
vendor_id=0x0403
product_id=0x6015
manufacturer="FTDI"
product="FT240X"
EOF

# Flash (may need to specify current VID/PID)
sudo ftdi_eeprom --flash-eeprom --device i:0x1209:0x3701 ftdi_restore.conf
```

## USB Device ID

| VID | PID | Description |
|-----|-----|---|
| 0x1209 | 0x3701 | Infinite Noise TRNG (pid.codes registered) |

The VID 0x1209 is provided by [pid.codes](https://pid.codes/), a registry for USB PID/VID for open source projects.

## Technical Details

### Health Monitoring

- Tracks 14 previous bits to predict next bit
- Uses fixed-point arithmetic (16.16 format)
- Requires ~80,000 bits warmup before data is valid
- Detects stuck-at faults (>20 consecutive identical bits)

## License

- Driver code: GPL-2.0-or-later
- Keccak implementation: CC0-1.0 (public domain)

## See Also

- [Infinite Noise TRNG Project](https://github.com/leetronics/infnoise)
- [Wayward Geek's Original Design](https://github.com/waywardgeek/infnoise)

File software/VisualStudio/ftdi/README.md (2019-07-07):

# FTDI driver required

Download FTDI Windows Drivers from [FTDI D2XX Drivers page](http://www.ftdichip.com/Drivers/D2XX.htm).

Using the latest `CDM v2.12.28 WHQL Certified.zip` driver archive, extract it to the `ftdi` folder:

The directory structure should be as follows:
```
    ftdi
	+--- README.md (existing)
    +--- amd64
    +--- i386
    +--- Static
        +--- amd64
        +--- i386
```

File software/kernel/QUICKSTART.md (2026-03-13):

# Switching to the Infinite Noise TRNG Kernel Module

This guide assumes you are currently using the userspace `infnoise` binary.

---

## Step 1: Stop the userspace daemon

```bash
sudo systemctl stop infnoise 2>/dev/null || true
sudo systemctl disable infnoise 2>/dev/null || true
sudo pkill rngd 2>/dev/null || true
sudo pkill infnoise 2>/dev/null || true
```

---

## Step 2: Check device VID/PID (one-time setup)

```bash
lsusb | grep -E "0403:6015|1209:3701"
```

- If you see **`1209:3701`** → skip to Step 4.
- If you see **`0403:6015`** → continue with Step 3.

---

## Step 3: Reprogram device EEPROM (only if VID/PID is 0403:6015)

**This permanently modifies the device. Only needed once per device.**

```bash
# Install ftdi_eeprom
sudo apt install ftdi-eeprom          # Debian/Ubuntu
# sudo dnf install ftdi-eeprom        # Fedora

# Unbind the FTDI serial driver
sudo modprobe -r ftdi_sio

# Flash the Infinite Noise VID/PID (infnoise-eeprom.conf is in this repo)
sudo ftdi_eeprom --flash-eeprom infnoise-eeprom.conf
```

Unplug and replug the device, then verify:

```bash
lsusb | grep 1209:3701
```

---

## Step 4: Install build prerequisites

```bash
sudo apt install linux-headers-$(uname -r) build-essential  # Debian/Ubuntu
# sudo dnf install kernel-devel gcc make                     # Fedora/RHEL
# sudo pacman -S linux-headers base-devel                    # Arch
```

---

## Step 5: Build and test the module

```bash
cd /path/to/infnoise/software/kernel
make
sudo make load
```

Check that the device was detected:

```bash
dmesg | grep infnoise
```

Read some random data to confirm it works:

```bash
sudo dd if=/dev/hwrng bs=64 count=4 | xxd
```

---

## Step 6: Install for automatic loading at boot

```bash
sudo cp infnoise.ko /lib/modules/$(uname -r)/extra/
sudo depmod -a
echo "infnoise" | sudo tee /etc/modules-load.d/infnoise.conf
```

Reboot and verify the module loaded automatically:

```bash
lsmod | grep infnoise
cat /sys/class/misc/hw_random/rng_current
```

---

## Done

The kernel module is now active. It automatically feeds entropy to the kernel — no `rngd` or any other daemon is needed.

To verify entropy is being generated:

```bash
# Check hwrng thread is running
ps aux | grep hwrng

# Quick FIPS test (requires rng-tools)
sudo dd if=/dev/hwrng bs=2500 count=100 | rngtest -c 100
```

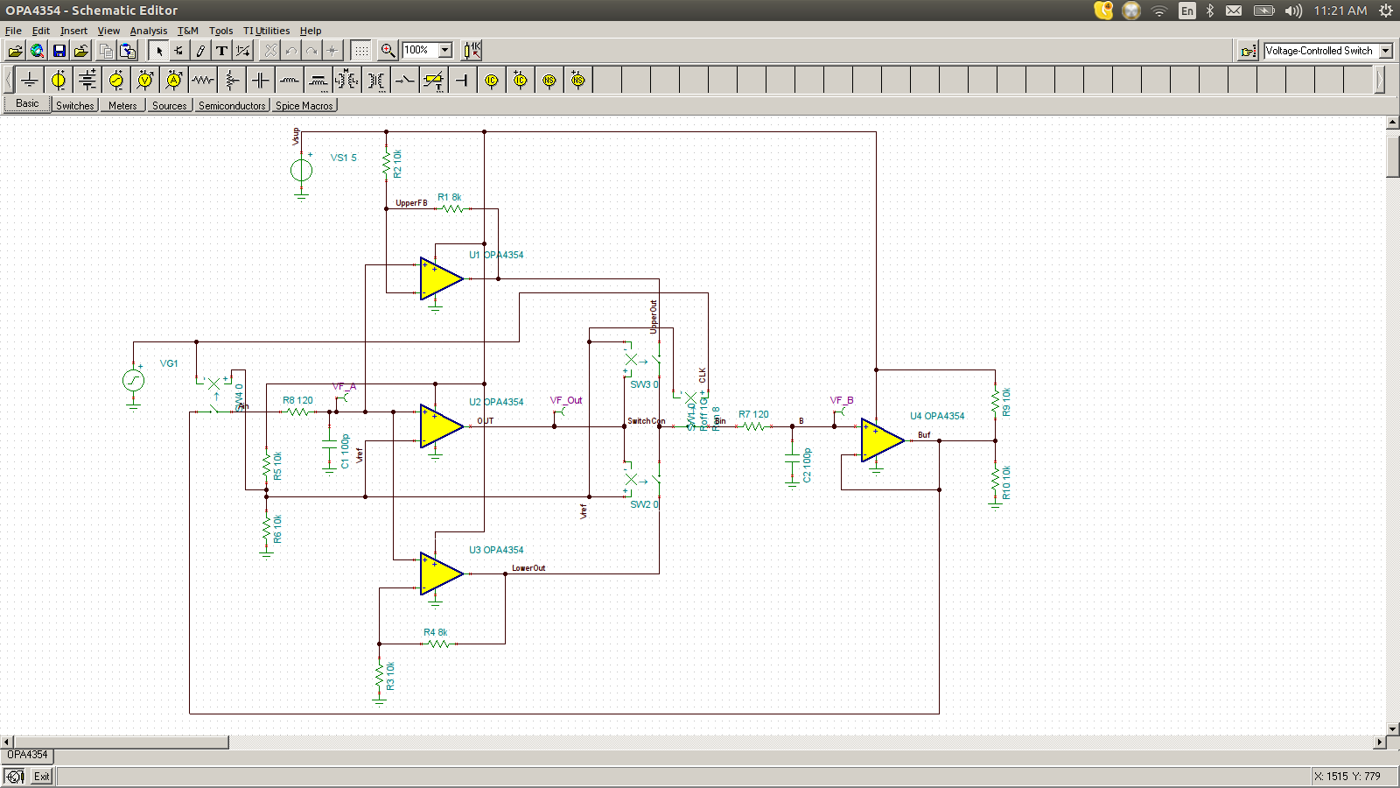
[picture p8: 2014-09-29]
infnoise_fast/schematic.png

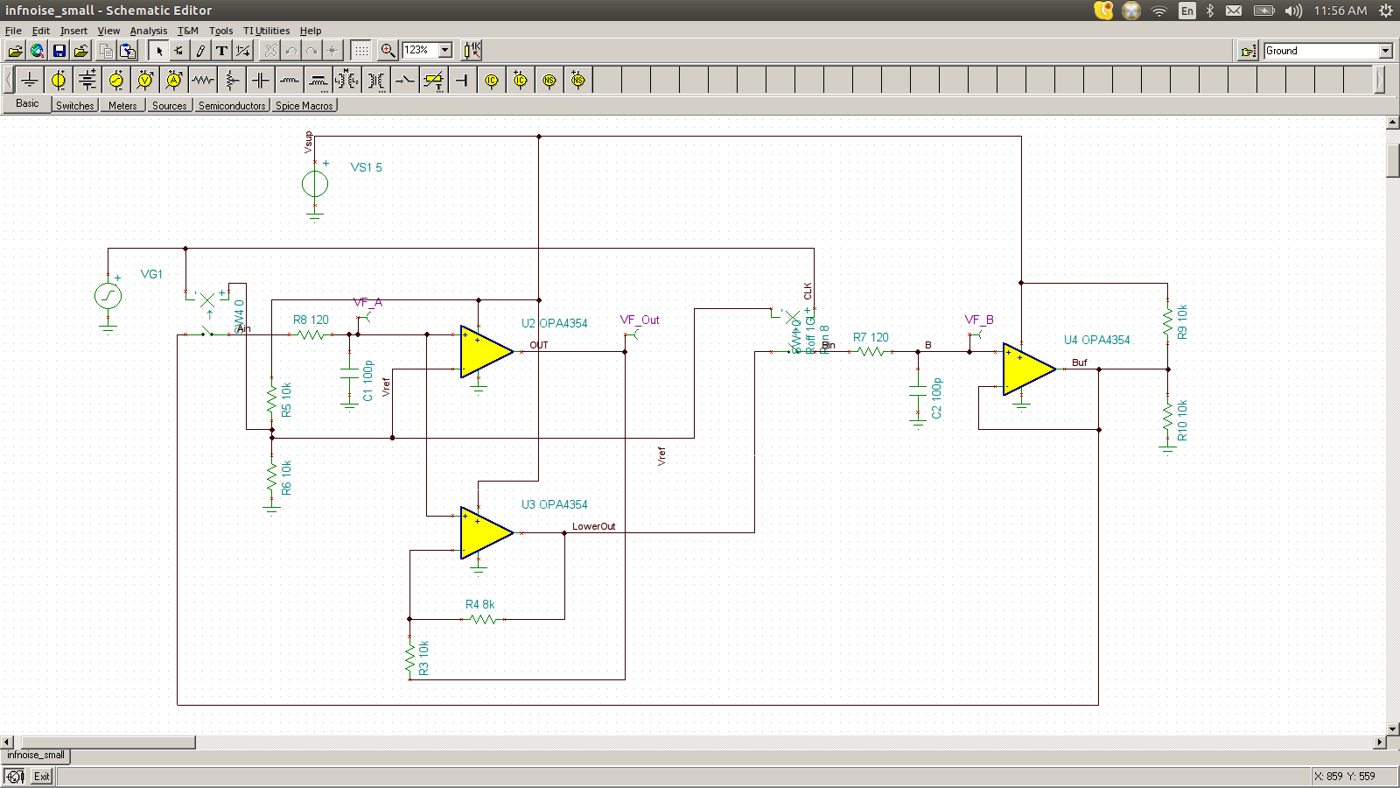
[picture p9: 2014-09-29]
infnoise_small/schematic.png

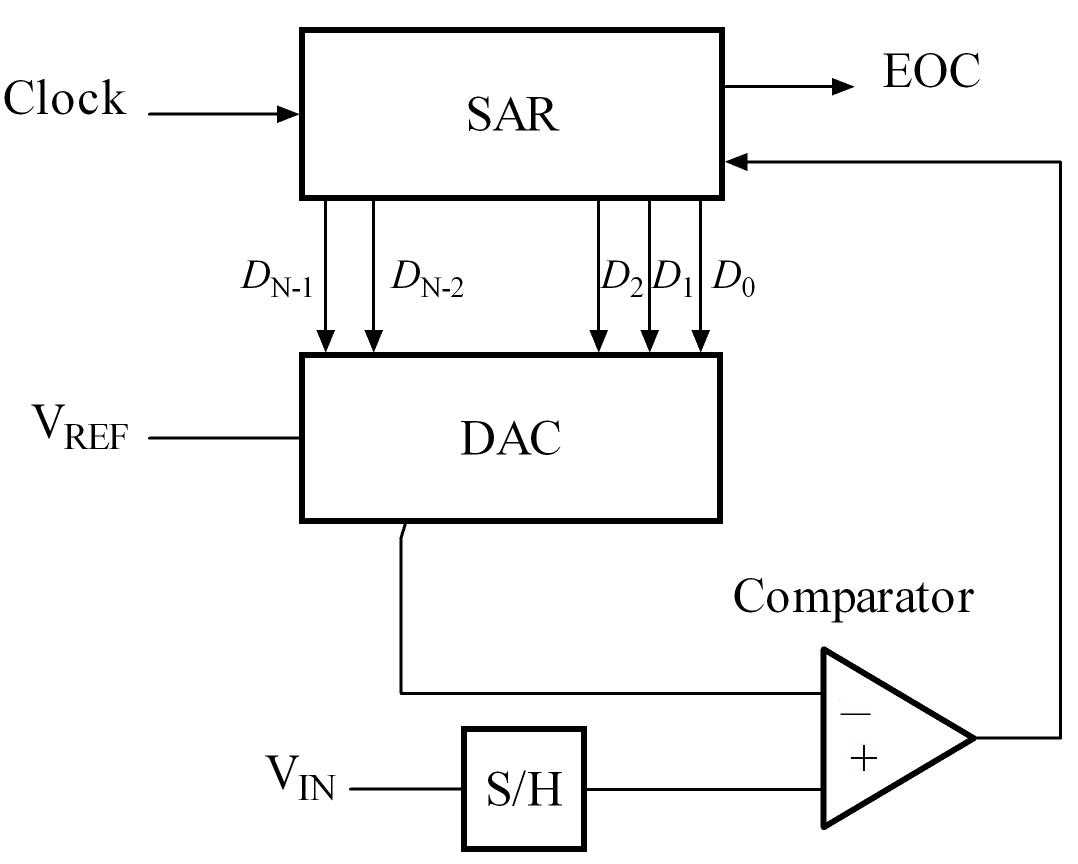
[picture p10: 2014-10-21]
images/SA_ADC_block_diagram.png

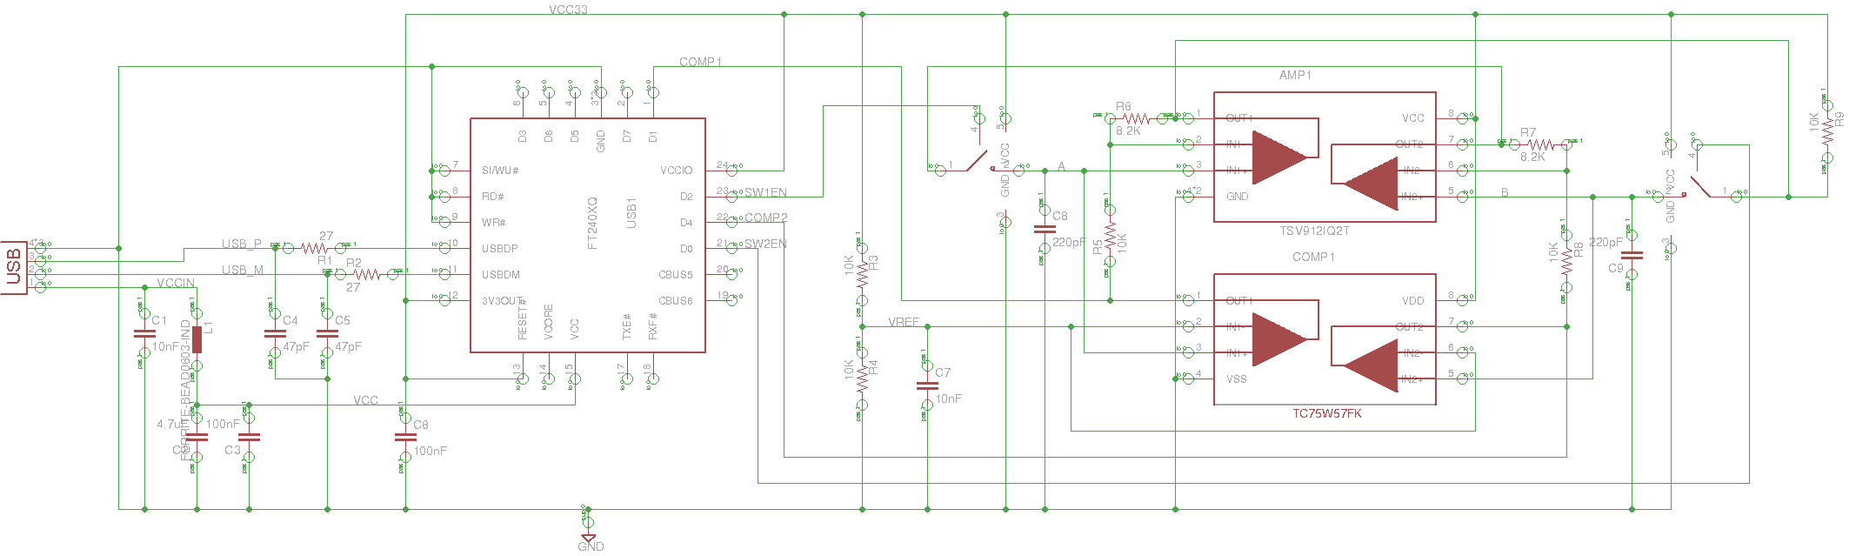
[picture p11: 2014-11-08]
images/infnoise.png

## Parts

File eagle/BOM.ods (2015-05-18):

Inf Noise Parts | Price | Buy size | Num used |  | Over-buy | Reel charge | Total Cost | Price | Buy size |  | Refs | Value | User supplied | Supplier | Sup. P/N | Man. P/N | Package | Notes
SPST switch | $0.07774 | 1000 | 2 | $0.15548 | 20% | $7.00 | $162.48 | $0.2364 | 25 | $0.4728 | SW1,SW2 |  | 1 | Digikey | MC74VHC1G66DFT1GOSCT-ND | MC74VHC1G66DFT1G | SC-70
Dual op-amp | $0.37950 | 1000 | 1 | $0.37950 | 20% | $7.00 | $386.50 | $0.8470 | 10 | $0.8470 | AMP |  | 1 | Digikey | 497-12414-1-ND | TSV912IQ2T | DFN8 (2x2mm)
Dual comparator | $0.29040 | 1000 | 1 | $0.29040 | 20% | $7.00 | $297.40 | $0.5700 | 10 | $0.5700 | CMP |  | 1 | Digikey | TC75W57FKTE85LFCT-ND | TC75W57FK | SSOP8-P-0.50A
220pF chip cap | $0.01020 | 1000 | 2 | $0.02040 | 20% | $7.00 | $27.40 | $0.0226 | 50 | $0.0452 | C8,C9 | 220pF | 1 | Digikey | 490-1435-1-ND | GRM1885C1H221JA01D | 0603-CAP
8.2K 1% resistors | $0.01711 | 1000 | 2 | $0.03422 | 20% | $7.00 | $41.22 | $0.0436 | 50 | $0.0872 | R6,R7 | 8.2K | 1 | Digikey | 541-8.20KHCT-ND | CRCW06038K20FKEA | 0603-RES
10K 1% resistors | $0.01711 | 1000 | 5 | $0.08555 | 20% | $7.00 | $92.55 | $0.0436 | 50 | $0.2180 | R3,R4,R5,R8,R9 | 10K | 0 | Digikey | 541-10.0KHCT-ND | CRCW060310K0FKEA | 0603-RES
10nF chip cap (see alternate) | $0.00465 | 1000 | 2 | $0.00930 | 20% | $7.00 | $16.30 | $0.0100 | 50 | $0.0200 | C1,C7 | 10nF | 0 | Digikey | GCM188R71E103KA37D-ND | GCM188R71E103KA37D | 0603-CAP | Alternate: GRM188R71H103KA01J/490-7213-1-ND
Total for Inf Noise Mult |  |  | 15 | $0.97485 |  |  | $1,023.85 |  |  | $2.2602 |  |  |  |  |  |  |  | Note: C1 is included up here, but is actually part of the USB interface
USB Related Parts
USB interface IC | $1.62260 | 1000 | 1 | $1.62260 | 20% | $7.00 | $1,629.60 | $2.4400 | 10 | $2.4400 | U1 |  | 1 | Digikey | 768-1157-ND | FT240XQ
.1uF bypass cap | $0.00480 | 10000 | 2 | $0.00480 | 20% | $7.00 | $55.00 | $0.0104 | 50 | $0.0104 | C3,C6 | 0.1uF | 0 | Digikey | 490-1524-1-ND | GRM188R71E104KA01D | 0603-CAP
Ferrite bead | $0.02153 | 1000 | 1 | $0.02153 | 20% | $7.00 | $28.53 | $0.0620 | 10 | $0.0620 | L1 |  | 1 | Digikey | 490-9702-1-ND | BLM18TG601TN1D | 0603-IND
4.7uf bypass cap | $0.02970 | 1000 | 1 | $0.02970 | 20% | $7.00 | $36.70 | $0.0634 | 50 | $0.0634 | C2 | 4.7uF | 1 | Digikey | 490-3302-1-ND | GRM188F51A475ZE20D | 0603-CAP
47pF chip cap | $0.00720 | 10000 | 2 | $0.01440 | 20% | $7.00 | $79.00 | $0.0156 | 50 | $0.0312 | C4,C5 | 47pF | 1 | Digikey | 490-1419-1-ND | GRM1885C1H470JA01D | 0603-CAP
27 Ohm resistor | $0.01711 | 1000 | 2 | $0.03422 | 20% | $7.00 | $41.22 | $0.0436 | 50 | $0.0872 | R1,R2 | 27 Ohms | 1 | Digikey | 541-27.0HCT-ND | CRCW060327R0FKEA | 0603-RES
USB SMT male conn | $0.70500 | 1000 | 1 | $0.70500 | 5% | $7.00 | $712.00 | $1.0900 | 10 | $1.0900 | X1 |  | 1 | Digikey | WM3983CT-ND | 480372200 | USB-A-SMT-MALE | From Molex
Enclosure | $1.45000 | 1000 | 1 | $1.45000 | 5% |  | $1,450.00 | $1.8000 | 10 | $1.8000 |  |  |  | Mouser | 789-P3A-140703-U | P-140703 |  | From New Age Enclosures: Buy with USB-A opening!
Boards from OshPark | $0.84556 | 900 | 1 | $0.84556 | 11% |  | $761.00 | $1.1700 | 12 | $1.1700
 |  |  | 10 | $4.72781 |  |  | $4,793.05 |  |  | $6.7542
Price/board in 1000 quantities | $5.82
 |  |  |  |  |  |  |  |  |  |  |  |  |  |  |  |  |  | Application of silver EMI shielding paint
EMI shielding | $1.00 | 1000 | 1 | $1.00000 |  |  | $0.00 |  |  |  |  |  |  |  |  |  |  | http://www.smallbatchassembly.com - will have to modify design
Assembly | $2.50 | 1000 | 1 | $2.50000 |  |  | $2,025.00 | 10 boards 15x6 = 9 to assemble + 1 spare
Test | $1.00 | 1000 | 1 | $1.00000 |  |  | $0.00 | Num boards: | 810
Standard mail w/ tracking | $1.20 | 1 | 1 | $1.20000 |  |  | $972.00 | See http://dbcalc.usps.com/CalculatorSetPage.aspx
Bubble envelope | $0.17 | 500 | 1 | $0.17000 |  |  | $170.00 |  |  |  |  |  | uline | S-8059
 |  |  |  | $5.87000 |  |  | $3,167.00
Subtotal |  |  |  | $11.57266 |  | Total cash | $8,983.90
Margin |  |  |  | 1.34 |  | Price/board | $11.09 | Note: margin includes EMI shielding and test charge, plus handling fee
 |  |  |  |  |  | After margin | $14.86
Tindie charges |  |  |  |  |  |  | $1.41467 | Tilndie charges only 5% + payment processing fee of 2.1-2.9% + $0.30
Total |  |  |  |  |  |  | $16.27692

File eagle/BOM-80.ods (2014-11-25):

Inf Noise Parts | Price | Buy size | Num used |  | Over-buy | Reel charge | Total Cost | Refs | Value | User supplied | Supplier | Sup. P/N | Man. P/N | Package | Notes
SPST switch | $0.12660 | 250 | 2 | $0.25320 | 20% | $7.00 | $38.65 | SW1,SW2 |  | 1 | Digikey | MC74VHC1G66DFT1GOSDKR-ND | MC74VHC1G66DFT1G | SC-70
Dual op-amp | $0.65220 | 100 | 1 | $0.65220 | 20% | $7.00 | $72.22 | AMP |  | 1 | Digikey | 497-12414-6-ND | TSV912IQ2T | DFN8 (2x2mm)
Dual comparator | $0.43920 | 100 | 1 | $0.43920 | 20% | $7.00 | $50.92 | CMP |  | 1 | Digikey | TC75W57FKTE85LFDKR-ND | TC75W57FK | SSOP8-P-0.50A
220pF chip cap | $0.01020 | 1000 | 2 | $0.02040 | 20% | $7.00 | $17.20 | C8,C9 | 220pF | 1 | Digikey | 490-1435-6-ND | GRM1885C1H221JA01D | 0603-CAP
8.2K 1% resistors | $0.01850 | 1000 | 2 | $0.03700 | 20% | $7.00 | $25.50 | R6,R7 | 8.2K | 1 | Digikey | 541-8.20KHDKR-ND | CRCW06038K20FKEA | 0603-RES
10K 1% resistors | $0.01850 | 1000 | 5 | $0.09250 | 20% | $7.00 | $25.50 | R3,R4,R5,R8,R9 | 10K | 0 | Digikey | 541-10.0KHDKR-ND | CRCW060310K0FKEA | 0603-RES
10nF chip cap (see alternate) | $0.00465 | 1000 | 2 | $0.00930 | 20% | $7.00 | $11.65 | C1,C7 | 10nF | 0 | Digikey | GCM188R71E103KA37D-ND | GCM188R71E103KA37D | 0603-CAP | Alternate: GRM188R71H103KA01J/490-7213-6-ND
Total for Inf Noise Mult |  |  | 15 | $1.50380 |  |  | $241.64 |  |  |  |  |  |  |  | Note: C1 is included up here, but is actually part of the USB interface
USB Related Parts
USB interface IC | $2.02000 | 100 | 1 | $2.02000 | 20% | $7.00 | $209.00 | U1 |  | 1 | Digikey | 768-1126-6-ND | FT240XQ
.1uF bypass cap | $0.00480 | 1000 | 2 | $0.00480 | 20% | $7.00 | $11.80 | C3,C6 | 0.1uF | 0 | Digikey | 490-1524-6-ND | GRM188R71E104KA01D | 0603-CAP
Ferrite bead | $0.13740 | 100 | 1 | $0.13740 | 20% | $7.00 | $20.74 | L1 |  | 1 | Digikey | 1276-6355-6-ND | CIC10J601NC | 0603-IND
4.7uf bypass cap | $0.05230 | 100 | 1 | $0.05230 | 20% | $7.00 | $12.23 | C2 | 4.7uF | 1 | Digikey | 490-3302-6-ND | GRM188F51A475ZE20D | 0603-CAP
47pF chip cap | $0.00720 | 1000 | 2 | $0.01440 | 20% | $7.00 | $14.20 | C4,C5 | 47pF | 1 | Digikey | 490-1419-6-ND | GRM1885C1H470JA01D | 0603-CAP
27 Ohm resistor | $0.02710 | 200 | 2 | $0.05420 | 20% | $7.00 | $12.42 | R1,R2 | 27 Ohms | 1 | Digikey | 541-27.0HDKR-ND | CRCW060327R0FKEA | 0603-RES
USB SMT male conn | $0.94020 | 100 | 1 | $0.94020 | 5% | $7.00 | $101.02 | X1 |  | 1 | Digikey | WM3983DKR-ND | 480372200 | USB-A-SMT-MALE | From Molex
Enclosure | $1.60000 | 100 | 1 | $1.60000 | 5% |  | $160.00 |  |  |  | Mouser | 789-P3A-140703-U | P-140703 |  | From New Age Enclosures: Buy with USB-A opening!
Boards from OshPark | $1.50000 | 100 | 1 | $1.50000 | 11% |  | $150.00
 |  |  | 10 | $6.32330 |  |  | $691.41
EMI shielding | $1.00 | 1000 | 1 | $1.00000 |  |  |  |  |  |  |  |  |  |  | Application of silver EMI shielding paint
Assembly | $9.50 | 1000 | 1 | $9.50000 |  |  |  |  |  |  |  |  |  |  | http://www.smallbatchassembly.com - will have to modify design
Test | $1.00 | 1000 | 1 | $1.00000
1st class mail | $1.50 | 1 | 1 | $1.50000
Bubble envelope | $0.17 | 500 | 1 | $0.17000 |  |  |  |  |  | uline | S-8059
 |  |  |  | $13.17000
Subtotal |  |  |  | $20.99710 |  | Up-front cash | $933.05
 |  |  |  |  |  | Assembly | $760.00
 |  |  |  |  |  | total | $1,693.05
 |  |  |  |  |  | Cost/board | $21.16

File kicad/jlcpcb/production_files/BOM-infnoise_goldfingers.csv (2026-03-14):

Comment | Designator | Footprint | LCSC | Quantity
27 Ω | R2 | R_0603_1608Metric |  | 1
47 pF | C5 | C_0603_1608Metric |  | 1
10 kΩ | R4 | R_0603_1608Metric |  | 1
27 Ω | R1 | R_0603_1608Metric |  | 1
10 kΩ | R5 | R_0603_1608Metric |  | 1
47 pF | C4 | C_0603_1608Metric |  | 1
220 pF | C8 | C_0603_1608Metric |  | 1
NS5B1G385DFT2G | SW2 | SOT-353_SC-70-5 |  | 1
0.01 µF | C7 | C_0603_1608Metric |  | 1
0.01 µF | C1 | C_0603_1608Metric |  | 1
TSV912IQ2T | AMP1 | DFN-8-1EP_2x2mm_P0.5mm_EP1.05x1.75mm |  | 1
FT240XQ | USB1 | QFN-24-1EP_4x4mm_P0.5mm_EP2.6x2.6mm |  | 1
10 kΩ | R3 | R_0603_1608Metric |  | 1
220 pF | C9 | C_0603_1608Metric |  | 1
0.1 µF | C3 | C_0603_1608Metric |  | 1
10 kΩ | R9 | R_0603_1608Metric |  | 1
0.1 µF | C6 | C_0603_1608Metric |  | 1
NS5B1G385DFT2G | SW1 | SOT-353_SC-70-5 |  | 1
TC75W57FKTE85LF | COMP1 | VSSOP-8_2.3x2mm_P0.5mm |  | 1
BLM18AG601SN1D | L1 | L_0603_1608Metric |  | 1
4.7 µF | C2 | C_0603_1608Metric |  | 1
10 kΩ | R8 | R_0603_1608Metric |  | 1
8.2 kΩ | R6 | R_0603_1608Metric |  | 1
8.2 kΩ | R7 | R_0603_1608Metric |  | 1

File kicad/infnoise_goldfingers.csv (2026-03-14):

Reference | Qty | Value | DNP | Exclude from BOM | Exclude from Board | Footprint | Datasheet
AMP1 | 1 | TSV912IQ2T |  |  |  | Package_DFN_QFN:DFN-8-1EP_2x2mm_P0.5mm_EP1.05x1.75mm | https://partdb.alfter.us/en/part/642/info
C1,C7 | 2 | 0.01 µF |  |  |  | Capacitor_SMD:C_0603_1608Metric | https://partdb.alfter.us/en/part/389/info
C2 | 1 | 4.7 µF |  |  |  | Capacitor_SMD:C_0603_1608Metric | https://partdb.alfter.us/en/part/274/info
C3,C6 | 2 | 0.1 µF |  |  |  | Capacitor_SMD:C_0603_1608Metric | https://partdb.alfter.us/en/part/264/info
C4,C5 | 2 | 47 pF |  |  |  | Capacitor_SMD:C_0603_1608Metric | https://partdb.alfter.us/en/part/638/info
C8,C9 | 2 | 220 pF |  |  |  | Capacitor_SMD:C_0603_1608Metric | https://partdb.alfter.us/en/part/639/info
COMP1 | 1 | TC75W57FKTE85LF |  |  |  | Package_SO:VSSOP-8_2.3x2mm_P0.5mm | https://partdb.alfter.us/en/part/643/info
FID1,FID2,FID3 | 3 | FIDUCIALUFIDUCIAL |  | Excluded from BOM |  | Fiducial:Fiducial_0.5mm_Mask1mm | ~
L1 | 1 | BLM18AG601SN1D |  |  |  | Inductor_SMD:L_0603_1608Metric | https://partdb.alfter.us/en/part/644/info
R1,R2 | 2 | 27 Ω |  |  |  | Resistor_SMD:R_0603_1608Metric | https://partdb.alfter.us/en/part/297/info
R3,R4,R5,R8,R9 | 5 | 10 kΩ |  |  |  | Resistor_SMD:R_0603_1608Metric | https://partdb.alfter.us/en/part/304/info
R6,R7 | 2 | 8.2 kΩ |  |  |  | Resistor_SMD:R_0603_1608Metric | https://partdb.alfter.us/en/part/641/info
SW1,SW2 | 2 | NS5B1G385DFT2G |  |  |  | Package_TO_SOT_SMD:SOT-353_SC-70-5 | https://partdb.alfter.us/en/part/648/info
USB1 | 1 | FT240XQ |  |  |  | Package_DFN_QFN:QFN-24-1EP_4x4mm_P0.5mm_EP2.6x2.6mm | https://partdb.alfter.us/en/part/637/info
X1 | 1 | USB_A |  | Excluded from BOM |  | USB-A-RAWPINS | ~

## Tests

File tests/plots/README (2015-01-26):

Thanks to Cor van Wandelen for writing these two programs, colormap.py and scatterplot.py.
He used these to create these png files from his inifinite noise TRNG.

To recreate similar plots, you can use data in the samples directory, and these commands:

$ cp ../samples/infnoise_raw.bin infnoise.bin
$ python colormap.py
$ python scatterplot.py

I created the raw data files with:

$ sudo ../software/infnoise --debug --raw > infnoise_raw.bin

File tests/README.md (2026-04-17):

# Entropy tests for the Infinite Noise TRNG

## Test results

These test results were produced with 250MiB 
(2.000.000.000 bits) of random numbers from the device,
resulting in 100.000 FIPS blocks with 20.000 bit each - and took two weeks.

### Output speed
|Multiplier/Mode|raw|whitened (SHA-3)|/dev/random|
|----|----|----|----|
| 0 | 50 KiB/s | 42,5 KiB/s | 0,3  KiB/s  |
| 1 | - | 25 KiB/s | 14,0 KiB/s  |
| 10 | - | 250  KiB/s | 23 KiB/s  |
| 100 | - | 2,25 MiB/s | 20,9 KiB/s  |
| 1000 | - | 17,2 MiB/s | 14,0 KiB/s  |
| 10000 | - | 68,3 MiB/s | 4,21 KiB/s  |

(*) with an Intel i7-4558U CPU @ 2.80GHz.

### FIPS Tests

| Multiplier/Mode | raw  | failed blocks (SHA-3) | failed blocks /dev/random |
|---|---|---|---|
| 0 | 99999| 70 (0,07 %)  | 81 (0,08 %)  |
| 1 | -  | 78 (0,08 %)  | 73 (0,07 %)  |
| 10 | -  | 87 (0,09 %)  | 89 (0,09 %)  |
| 100 | -  | 87 (0,09 %)  | 95 (0,1 %) |
| 1000 | -  | 78  (0,08 %)  | 73 (0,07 %) |
| 10000 | -  | 74  (0,07 %)  | 86  (0,09 %)  |

* The percentage of failed FIPS blocks should always remain below 0,1%. 

## Run your own tests

### Requirements

Make sure you have the following tools installed:

- rng-tools (make sure to stop rngd during the test and uninstall/disable afterwards)
- ent
- dieharder
- pv
- python (numpy, matplotlib)
- infnoise driver

In the header of the script, you can define the test parameters:
```
declare -a TEST_KBYTES=('25000')
declare -a TEST_MULTIPLIERS=('0' '1' '10' '100' '1000' '10000')
```
A full test run like this with 25MiB takes almost 2 days, mostly because of /dev/random 
tests with a multiplier of zero.

This is why by default it performs a reduced run which takes only 1-2 hours.

Tests are run for each combination of these parameters and can be started by running runtests.sh:
```
$ git clone https://github.com/leetronics/infnoise
$ cd tests
$ sudo ./runtests.sh
```
The output directories will be created automatically.

## Files and Directories:
Directory structure created by a test run:

	- results: 
	  - <testcase>-<multiplier>-<kbytes>-dieharder.txt
	  - <testcase>-<multiplier>-<kbytes>-ent.txt
	  - <testcase>-<multiplier>-<kbytes>-rngtest.txt
	  - plots:
	    - <testcase>-<multiplier>-<kbytes>K.out-colormap.png: 	square distribution
	    - <testcase>-<multiplier>-<kbytes>K.out-scatterplot.png:	scatter plots
	  - data:
	    - <testcase>-<multiplier>-<kbytes>K.log: 			log output of the infnoise utility
	    - <testcase>-<multiplier>-<kbytes>K-pv.log: 		log output of pv
	    - <testcase>-<multiplier>-<kbytes>K.out:			random data produced in the test run

In the already existing results folder you'll find results for major driver [releases] (https://github.com/leetronics/infnoise/releases).

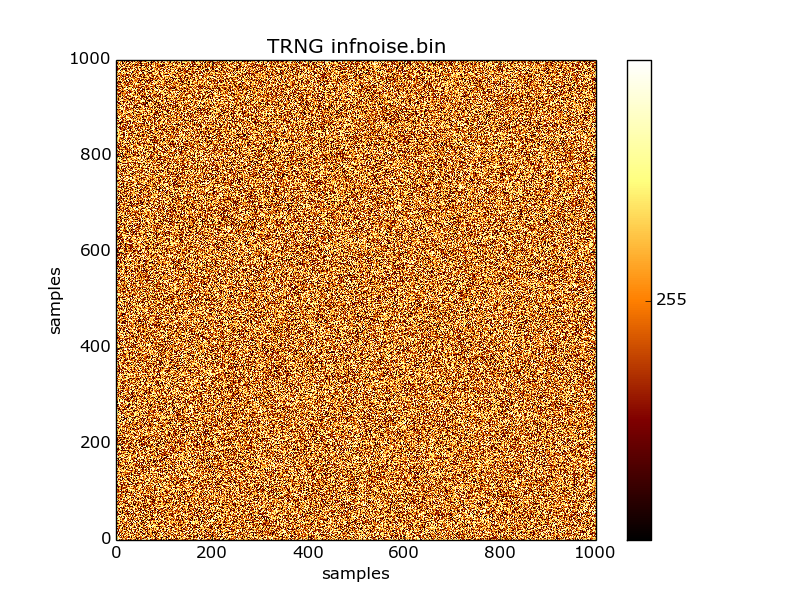
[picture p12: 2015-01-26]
tests/plots/infnoise.bin-colormap.png

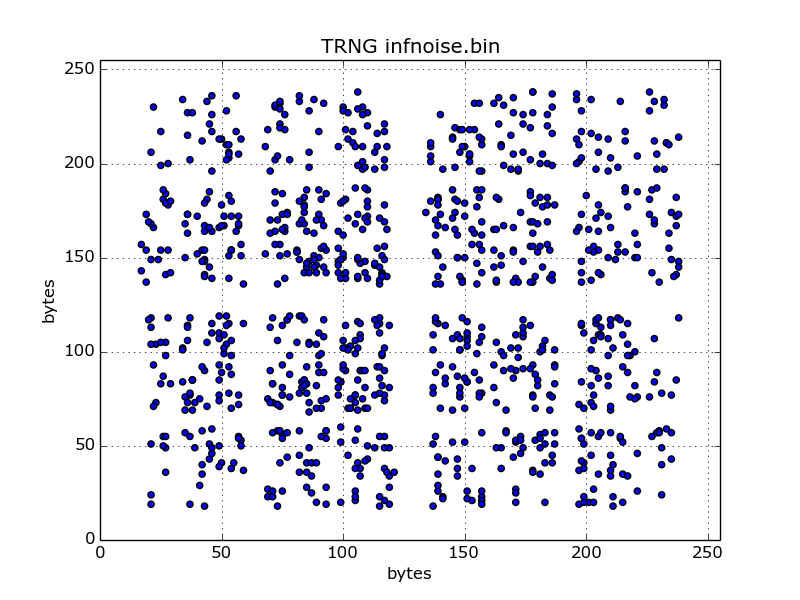
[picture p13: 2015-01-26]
tests/plots/infnoise.bin-scatter.png

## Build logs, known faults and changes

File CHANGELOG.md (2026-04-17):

# Change Log

## [0.3.0](https://github.com/leetronics/infnoise/tree/0.3.0) (2018-10-09)
[Full Changelog](https://github.com/leetronics/infnoise/compare/0.2.6...0.3.0)

**Merged pull requests:**

- merge libinfnoise branch [\#12](https://github.com/leetronics/infnoise/pull/12) ([manuel-domke](https://github.com/manuel-domke))
- Fix apt-key add command in README [\#11](https://github.com/leetronics/infnoise/pull/11) ([xenomachina](https://github.com/xenomachina))
- Fix a couple of spelling errors [\#10](https://github.com/leetronics/infnoise/pull/10) ([skitt](https://github.com/skitt))

## [0.2.6](https://github.com/leetronics/infnoise/tree/0.2.6) (2018-05-02)
[Full Changelog](https://github.com/leetronics/infnoise/compare/0.2.5...0.2.6)

**Closed issues:**

- systemd service can't be disabled [\#7](https://github.com/leetronics/infnoise/issues/7)

## [0.2.5](https://github.com/leetronics/infnoise/tree/0.2.5) (2018-04-09)
[Full Changelog](https://github.com/leetronics/infnoise/compare/0.2.4...0.2.5)

## [0.2.4](https://github.com/leetronics/infnoise/tree/0.2.4) (2018-04-02)
[Full Changelog](https://github.com/leetronics/infnoise/compare/0.2.3...0.2.4)

## [0.2.3](https://github.com/leetronics/infnoise/tree/0.2.3) (2018-03-02)
[Full Changelog](https://github.com/leetronics/infnoise/compare/0.2.2...0.2.3)

## [0.2.2](https://github.com/leetronics/infnoise/tree/0.2.2) (2018-03-01)
[Full Changelog](https://github.com/leetronics/infnoise/compare/0.2.0...0.2.2)

## [0.2.0](https://github.com/leetronics/infnoise/tree/0.2.0) (2018-03-01)
[Full Changelog](https://github.com/leetronics/infnoise/compare/0.2.1...0.2.0)

## [0.2.1](https://github.com/leetronics/infnoise/tree/0.2.1) (2018-03-01)
[Full Changelog](https://github.com/leetronics/infnoise/compare/v0.2.1...0.2.1)

## [v0.2.1](https://github.com/leetronics/infnoise/tree/v0.2.1) (2018-03-01)
[Full Changelog](https://github.com/leetronics/infnoise/compare/v0.2.0...v0.2.1)

**Merged pull requests:**

- Version number [\#5](https://github.com/leetronics/infnoise/pull/5) ([manuel-domke](https://github.com/manuel-domke))
- Correct CS spelling [\#4](https://github.com/leetronics/infnoise/pull/4) ([darrellrossman](https://github.com/darrellrossman))

## [v0.2.0](https://github.com/leetronics/infnoise/tree/v0.2.0) (2017-12-31)
[Full Changelog](https://github.com/leetronics/infnoise/compare/v0.1.2...v0.2.0)

**Merged pull requests:**

- merged captainpete's pull request \#28 from waywardgeek/infnoise [\#3](https://github.com/leetronics/infnoise/pull/3) ([manuel-domke](https://github.com/manuel-domke))
- merged "increased timeout and options struct" pull request from runema [\#2](https://github.com/leetronics/infnoise/pull/2) ([manuel-domke](https://github.com/manuel-domke))

## [v0.1.2](https://github.com/leetronics/infnoise/tree/v0.1.2) (2017-11-13)
[Full Changelog](https://github.com/leetronics/infnoise/compare/0.1.0...v0.1.2)

**Merged pull requests:**

- updated readme [\#1](https://github.com/leetronics/infnoise/pull/1) ([manuel-domke](https://github.com/manuel-domke))

## [0.1.0](https://github.com/leetronics/infnoise/tree/0.1.0) (2017-08-29)
[Full Changelog](https://github.com/leetronics/infnoise/compare/0.1.1...0.1.0)

## [0.1.1](https://github.com/leetronics/infnoise/tree/0.1.1) (2017-08-29)
[Full Changelog](https://github.com/leetronics/infnoise/compare/Fourth-OshPark-Prototype...0.1.1)

## [Fourth-OshPark-Prototype](https://github.com/leetronics/infnoise/tree/Fourth-OshPark-Prototype) (2014-11-02)
[Full Changelog](https://github.com/leetronics/infnoise/compare/Third-OshPark-Prototype...Fourth-OshPark-Prototype)

## [Third-OshPark-Prototype](https://github.com/leetronics/infnoise/tree/Third-OshPark-Prototype) (2014-10-15)
[Full Changelog](https://github.com/leetronics/infnoise/compare/Second-OshPark-Prototype...Third-OshPark-Prototype)

## [Second-OshPark-Prototype](https://github.com/leetronics/infnoise/tree/Second-OshPark-Prototype) (2014-10-12)
[Full Changelog](https://github.com/leetronics/infnoise/compare/First-OshPark-Prototype...Second-OshPark-Prototype)

## [First-OshPark-Prototype](https://github.com/leetronics/infnoise/tree/First-OshPark-Prototype) (2014-10-10)

\* *This Change Log was automatically generated by [github_changelog_generator](https://github.com/skywinder/Github-Changelog-Generator)*

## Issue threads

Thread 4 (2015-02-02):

Driver support for more than one device

tqz, 2015-02-02:
The GNU/Linux version of the driver only discovers and uses the first device. Please add support for multiple devices.

manuel-domke, 2017-08-29:
Just implemented this in #26

waywardgeek, 2017-08-29:
I just pulled a fix for this.  Thanks, Manuel!

Closed 2017-08-29.

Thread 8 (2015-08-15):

Windows driver generates extra 0D characters

jironpech, 2015-08-15:
The windows driver unhelpfully appends a hex 0D "character" to every instance of an 0A in the file it writes to make the familiar 0D 0A. This is a typical problem with text files shared between Linux and Windows, but the file should be defined as a binary type so this does not happen. A simple analysis of the file using HxD shows that the 0D bytes are twice as common as everything else. This ruins the entropy, of course.

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

waywardgeek, 2015-08-17:
Well, crips!  I thought that bug was put to rest ages ago.  It probably
re-occurred when I pulled a Windows update.  The latest way to open the
output file is:

outFile = _fsopen(argv[xArg], "w", _SH_DENYWR);

Should it be "wb"?

Thanks for catching this!
Bill

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

jironpech, 2015-08-18:
OK, that narrows it down a lot - I'll play with that line.

waywardgeek, 2015-08-18:
Thanks!  I have limited access to Windows machines currently, so if you can
verify a fix, that would help a lot.

Bill

On Tue, Aug 18, 2015 at 12:25 PM, jironpech <notifications@github.com>
wrote:

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

jironpech, 2015-08-18:
Verified - "wb" fixes the output, so thanks for the tip. I can contribute a compiled binary and a few details in the documentation if that helps.

waywardgeek, 2015-08-18:
Actually, it would, if you don't mind :)

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

jironpech, 2015-08-23:
OK, I created a branch that fixes the 0D error. I also fixed some pathname problems in the VS solution. The latest "daemon" updates broke the windows build. This line in infnoise.h is the culprit:
int writePid(pid_t pid, char *fileName);

I don't know if the daemon is intended for the windows version; it sounds like it might be an OS specific tweak. Anyway, the windows and linux versions may not be able to share a header file anymore unless this line can be moved somewhere else or the daemon function can be ported to windows.

As a quick fix I established a new header file for the windows build that omits this line.

I'm not sure how this "pull request" stuff works. What's the best way to review and incorporate these changes?

waywardgeek, 2015-08-24:
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
This was a bug.  I changed that declaration to make it portable.

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
I merged your changes, and switched back to using infnoise.h.  If you get a
chance, it would be great if you could test that the merged version
compiles in Windows.  I manually edited a couple vcproj files where
infnoise_win.h occurred, and changed them to infnoise.h, and I am not sure
I got it right.

Thanks for the patch!

Bill

jironpech, 2015-08-25:
The windows version compiles perfectly - issue closed! Nice teamwork...

waywardgeek, 2015-08-25:
Thanks for helping out!

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

Closed 2015-08-25.

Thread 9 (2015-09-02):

FTDI chip & code injection

alphazo, 2015-09-02:
The FTDI chip USB/UART interface is a microcontroller and its firmware can be updated over USB. Could that not be a threat so when you plug the dongle in a rogue computer, it changes the FTDI firmware so it manipulates the raw random data stream before sending it over to the host computer?

waywardgeek, 2015-09-02:
Is the firmware upgradeable?  I have not seen this capability in the API
docs.

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

alphazo, 2015-09-02:
Sorry I think I may have a looked at the wrong FTDI part number. The one used in this design seems to only have provision for re-programming USB configuration descriptors via FT_PROG and not the whole firmware.

waywardgeek, 2015-09-02:
Honestly, a concern I still have is that FTDI may have at some point
switched to a simple common microcontroller based design used between their
various products, and only publicly described the config registers.  The
MiB (Men in Black) might have power to intercept these and reconfigure them
without having to modify the board at all.

So... I wind up in the typical case of having to trust my IC vendors...

Bill

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

Closed 2017-08-29.

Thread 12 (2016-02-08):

Add information for using infnoise with udev

AbigailBuccaneer, 2016-02-08:
`software/README` talks about running as a daemon, and using `rngd` to add entropy from a FIFO to `/dev/random`. However, it's possible to use `udev` to start the daemon whenever the infnoise is plugged in, as so:

```
$ cat /etc/udev/rules.d/75-infnoise.rules
ACTION=="add", SUBSYSTEM=="usb", ATTRS{idVendor}=="0403", ATTRS{idProduct}=="6015", RUN+="/usr/local/bin/infnoise --dev-random --daemon"
```

Many similar software packages for hardware will ship udev rules in the repository with instructions on how to add the rules and check that they're working. I think this would be useful for infnoise, as it provides the lowest-friction way to use the infnoise.

If you think this would be useful in the repository, I can make a pull request with a rules file and instructions on how to use it (and maybe even `make` rules to install infnoise and the rules).

waywardgeek, 2016-02-08:
Thanks, Abigail!  I added your udev file at the end of the README to
start.  Maybe it makes sense to have it as a make option.  My only
hesitation is that even this super-simple Makefile is already not portable
across Linux distros (it does not work on Fedora, for example).  I prefer
not to include distro-specific stuff.

Thanks,
Bill

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

letoff, 2016-02-20:
Hi there,

I have some problems running infnoise with this method. When I run it from the command line everything runs smoothly and I can generate random nums for hours with gpg.
But when the same command (i.e /usr/local/bin/infnoise --dev-random --daemon) is executed by the udev rule above it crash after a while (generally a few seconds).

Here is what strace says:

`select(5, NULL, [4], NULL, {0, 1000})   = 1 (out [4], left {0, 982})
ioctl(4, USBDEVFS_REAPURBNDELAY, 0x7fff171a38f8) = 0
ioctl(4, USBDEVFS_SUBMITURB, 0x7fff171a3930) = 0
ioctl(4, USBDEVFS_REAPURBNDELAY, 0x7fff171a38f8) = -1 EAGAIN (Resource temporarily unavailable)
select(5, NULL, [4], NULL, {0, 1000})   = 1 (out [4], left {0, 993})
ioctl(4, USBDEVFS_REAPURBNDELAY, 0x7fff171a38f8) = 0
ioctl(3, RNDGETENTCNT, 0x7fff171a3a8c)  = 0
poll([{fd=3, events=POLLOUT}], 1, 1000) = 0 (Timeout)
ioctl(3, RNDADDENTROPY, 0x11b9010)      = 0
ioctl(4, USBDEVFS_SUBMITURB, 0x7fff171a3960) = -1 EBUSY (Device or resource busy)
write(2, "USB write failed\n", 17)      = -1 EPIPE (Broken pipe)
--- SIGPIPE {si_signo=SIGPIPE, si_code=SI_USER, si_pid=2527, si_uid=0} ---
exit_group(-1)                          = ?
+++ exited with 255 +++
`
So I guess it has something to do with ftdi_write_data. Any idea why it works fine when executed  from command line and not from udev rule ?

letoff, 2016-02-20:
And BTW there seems to be a zombie process just after plugin-in the device:

asusport ~ # ps faux|grep infnoise
root      1002  0.0  0.0      0     0 ?        Z    16:43   0:00      \_ [infnoise] <defunct>
root      1005  0.0  0.0  12748  2192 pts/1    S+   16:43   0:00  |           \_ grep infnoise
root      1003  0.5  0.0  16024  2088 ?        S    16:43   0:00 /usr/local/bin/infnoise --dev-random --daemon

mrplumber, 2016-08-17:
Hello,

This method doe's not work on Debian Jessie.

Here is relevant dmesg output on device insertion:

[83350.556035] usb 2-4: new full-speed USB device number 18 using ohci-pci
[83350.787052] usb 2-4: New USB device found, idVendor=0403, idProduct=6015
[83350.792483] usb 2-4: New USB device strings: Mfr=1, Product=2, SerialNumber=3
[83350.797963] usb 2-4: Product: FT240X USB FIFO
[83350.803363] usb 2-4: Manufacturer: FTDI
[83350.808681] usb 2-4: SerialNumber: DN004WRD
[83350.822111] ftdi_sio 2-4:1.0: FTDI USB Serial Device converter detected
[83350.828454] usb 2-4: Detected FT-X
[83350.833961] usb 2-4: Number of endpoints 2
[83350.839446] usb 2-4: Endpoint 1 MaxPacketSize 64
[83350.844883] usb 2-4: Endpoint 2 MaxPacketSize 64
[83350.850146] usb 2-4: Setting MaxPacketSize 64
[83350.863116] usb 2-4: FTDI USB Serial Device converter now attached to ttyUSB0
[83351.068409] ftdi_sio ttyUSB0: FTDI USB Serial Device converter now disconnected from ttyUSB0
[83351.074254] ftdi_sio 2-4:1.0: device disconnected
[83382.640061] usb 2-4: usbfs: process 6260 (infnoise) did not claim interface 0 before use

Here is relevant journalctl output:

<...> same as above <...>
Aug 17 16:17:33 homeserv kernel: ftdi_sio ttyUSB0: FTDI USB Serial Device converter now disconnected from ttyUSB0
Aug 17 16:17:33 homeserv kernel: ftdi_sio 2-4:1.0: device disconnected
Aug 17 16:18:03 homeserv systemd-udevd[6258]: timeout '/usr/local/bin/infnoise --dev-random --daemon'
Aug 17 16:18:04 homeserv kernel: usb 2-4: usbfs: process 6260 (infnoise) did not claim interface 0 before use
Aug 17 16:18:34 homeserv systemd-udevd[6258]: timeout '/usr/local/bin/infnoise --dev-random --daemon'

If started by user from console runs as expected.

manuel-domke, 2017-07-25:
Actually, using udev for this is not the right way, as we want to start a daemon which is not the idea of udev.

Thats why all the problems arise..
Jul 25 17:57:23 zen systemd-udevd[616]: seq 3118 '/devices/pci0000:00/0000:00:14.0/usb1/1-1/1-1:1.0' is taking a long time
Jul 25 17:59:23 zen systemd-udevd[616]: seq 3118 '/devices/pci0000:00/0000:00:14.0/usb1/1-1/1-1:1.0' killed

I'm gonna try to write a systemd device unit, which will hopefully do the job.

waywardgeek, 2017-08-29:
Is everything working OK with udev now?  If so, I'll close this issue.

Closed 2018-09-10.

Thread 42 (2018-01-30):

Sample dieharder output?

proegssilb, 2018-01-30:
I came here from the Crowd Supply campaign, and was wondering if you felt comfortable (or that it was a wise idea) to post some of the results you've seen from dieharder. It'd be even cooler if they were generated by a CI server, but having any results at all would be nice.

waywardgeek, 2018-02-01:
It "passed" Dieharder long ago.  There's a web-site that has results from
many devices, but I'm not able to find it at the moment.

On Mon, Jan 29, 2018 at 5:56 PM, David Bliss <notifications@github.com>
wrote:

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

manuel-domke, 2018-02-03:
I'm working on a testsuite for the Infinite Noise, to be integrated into the CI server for building the linux packages.
You can find the current work in progress here: https://files.13-37.org/tests
(dieharder tests are still running)

The test results will be examined in detail during the crowdsupply campaign - so stay tuned!

proegssilb, 2018-02-03:
Very promising! Any chance those results can be linked to from a readme somewhere?

I think with a clear answer to that, we can close this out.

manuel-domke, 2018-02-03:
Yes, I'll commit results for some longer-run tests when they're done.
Just leave the issue open until then.

manuel-domke, 2018-04-10:
uploaded them here a while ago: https://github.com/waywardgeek/infnoise/tree/master/tests/results_250000K

Closed 2018-04-10.

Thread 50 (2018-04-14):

Linux kernel driver for in-kernel users of infnoise

sbates130272, 2018-04-14:
Great project! Has anyone looked at an in-kernel version of infnoise to provide TRNG services to other parts of the kernel? It could also expose the infnoise devices in the device tree to make consumption by user-space easier?

sbates130272, 2018-04-14:
Perhaps modelled on something that already exists in the kernel like:

https://git.kernel.org/pub/scm/linux/kernel/git/torvalds/linux.git/tree/drivers/usb/misc/chaoskey.c?h=v4.16

manuel-domke, 2018-04-18:
Also thought about this, but its probably a long road to go and I'm not so sure if whitening has its place in a kernel driver.

Anyway, the Infinite Noise TRNG driver can feed the kernels entropy pool so other "parts" can access its entropy.
Or am I wrong? Is there a downside of the current approach I'm not aware of?

I think we should stick to the libinfnoise idea (#51) for integration in custom applications and infnoise for use with shell scripts or /dev/random mode. (for now)

Based on the lib it will be a lot easier to implement a kernel driver.

Closed 2018-10-12.

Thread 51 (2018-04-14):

libinfnoise

sbates130272, 2018-04-14:
Hi

Awesome project ;-). Right now infnoise compiles as a executable. Could we develop a libinfnoise target for both windows and Linux so it's easier for people to pull the TRNG streams into their user-space applications?

Stephen

manuel-domke, 2018-04-18:
I've worked on the interface, see

```
bool listUSBDevices(struct ftdi_context *ftdic, struct inm_devlist **result, char **message);

bool initInfnoise(struct ftdi_context *ftdic, char *serial, bool debug);

bool initKeccak(struct ftdi_context *ftdic, char *serial);

uint64_t readRawData(struct ftdi_context *ftdic, uint8_t *result);

uint64_t readData(struct ftdi_context *ftdic, uint8_t *keccakState, uint8_t *result, uint32_t outputMultiplier);

```

The infnoise binary still has dependancies to libinfnoise_private.h, which are really hard to avoid without duplicating lots of code - but I think its pretty OK this way.

Still some stuff to clean up and fix - but this could become a release candidate soon.

manuel-domke, 2018-04-22:
I created pull request #55 for the current state of work.

libinfnoise is usable for now, but the interface may change. Feedback wanted!

manuel-domke, 2018-07-17:
I've opened another fork for furt libinfnoise developments.

My next goal is to fully separate input and output, so libinfnoise can be used independently.

https://github.com/13-37-org/infnoise/tree/libinfnoise/software

manuel-domke, 2018-09-10:
IMO the refactoring is done. This is how the interface finally looks:

    // initialize device
    bool initInfnoise(struct infnoise_context *context, char *serial, bool keccak, bool debug);

    // reads data in chunks of 32-128KB, depending in multiplier
    uint32_t readData(struct infnoise_context *context, uint8_t *result, bool raw, uint32_t outputMultiplier);

    // returns a struct listing the connected (FTDI) devices.
    devlist_node listUSBDevices(char **message);

Closed 2018-09-10.

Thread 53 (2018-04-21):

Incorrect linker flag (-lftdi) used because ldconfig not in path

jdimpson, 2018-04-21:
https://github.com/waywardgeek/infnoise/blob/fc0d99f58fff60b5cb7dca583f4bbcc60e1f63a2/software/Makefile#L14

Building on a Debian 9.4 amd64 system (up-to-date as of 3 day ago), with the official debian libftdi-dev package installed, which is at version 0.20-4. The infnoise software Makefile chose the wrong linker flag, apparently. Here's the output of `make`:
```
/bin/sh: 1: ldconfig: not found
cc -Wall -Wextra -Werror -std=c99 -O3 -I Keccak -I /usr/include/libftdi1 -DGIT_VERSION=\"Fourth-OshPark-Prototype-250-gfc0d99f\" -DGIT_COMMIT=\"fc0d99f58fff60b5cb7dca583f4bbcc60e1f63a2\" -DGIT_DATE=\"2018-04-10T06:52:23+02:00\" -DBUILD_DATE=\"2018-04-21T01:09:01-04:00\" -o infnoise infnoise.c healthcheck.c writeentropy.c daemon.c Keccak/KeccakF-1600-reference.c -lftdi1 -lm -lrt
/usr/bin/ld: cannot find -lftdi1
collect2: error: ld returned 1 exit status
Makefile:24: recipe for target 'infnoise' failed
make: *** [infnoise] Error 1
```

On Debian systems, `ldconfig` is found in `/sbin`, which is not in my unprivileged user's path. So the invocation of `ldconfig` failed, the FOUND variable was left empty, and thus the FTDI variable was set to `-lftdi1` rather than `-lftdi`.

I changed the invocation of `ldconfig` to `/sbin/ldconfig` and the compilation was successful.

I notice that `libftdi-config` is installed in `/usr/bin`. When I run it as `libftdi-config --libs`, it prints `-L/usr/lib/x86_64-linux-gnu -lftdi -lusb`. That may be a more robust way to find the linker arguments.

Thank you!

manuel-domke, 2018-04-21:
Thanks for the suggestion with libftdi-config.
As it comes with libftdi-dev its a good option.

Closed 2018-04-22.

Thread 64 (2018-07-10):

OSX instructions or binaries?

rorobaba, 2018-07-10:
How would one run the device on OSX?

manuel-domke, 2018-07-10:
Hi,

please check these issues/pull requests for the current state of work:

- "FreeBSD and macOS support": https://github.com/13-37-org/infnoise/issues/8
- "Fixed macOS build, documentation tweaks": https://github.com/manuel-domke/infnoise/pull/3

The already merged request's README including a section on how to compile on Mac:
https://github.com/manuel-domke/infnoise/blob/master/software/README.md

I'm working on getting all the required to this repo, but there is a lot of stuff coming together (libinfnoise refactoring (#51), cmake (https://github.com/13-37-org/infnoise/tree/cmake))

manuel-domke, 2018-09-10:
Now merged everything I'm aware of. If something is still missing / not working, please let me know.

Just got my first Mac(Book) so I can start learning how to use it (and compile infnoise..). So hopefully I can test on Mac by myself soon!

Closed 2018-10-12.

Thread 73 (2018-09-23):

Updated Arch PKGBUILD

AidanGG, 2018-09-23:
I tweaked the PKGBUILD to be more inline with AUR packaging requirements. It's for a potential `infnoise-git` package that someone might want to maintain on the AUR (could be me if desired).

[PKGBUILD](https://github.com/waywardgeek/infnoise/files/2408888/PKGBUILD.txt)

manuel-domke, 2018-10-12:
Yes. Thanks a lot for your improvements. I already merged most of them to the PKGBUILD.arch file under build-scripts.

Feel free to maintain the AUR packages, but please stick to the releases from the  13-37-org (or at least the versioning scheme, if you want to release more often)

AidanGG, 2018-10-12:
Ok, that sounds good. I'll post something up on the AUR soon.

AidanGG, 2018-10-12:
Alright, I've posted the first package on the AUR: [`infnoise-git`](https://aur.archlinux.org/packages/infnoise-git/). This one is a `-git` package, so it will build the latest commit from this repo. I am planning on creating an `infnoise` package which builds the latest release.

manuel-domke, 2018-10-12:
Usually I create signed packages for release builds - also for ArchLinux.

Maybe GPG signing is not needed for AUR packages at all - as the source is coming from Github and your package building process is transparent enough to make sure the binary comes from a unmodified check-out?

AidanGG, 2018-10-12:
So this `-git` package probably doesn't need GPG signing due to coming from GitHub like you said, but also since this package builds the latest commit on the 13-37-org repo, you wouldn't have signed each individual commit.

For the stable `infnoise` AUR package that I'm planning, usually they're built by taking some sort of archive (e.g. `tar.xz`) of the source for that git tag. You can also attach a signature to that archive (`.tar.xz.asc`) which can be used to verify the integrity of the source.

manuel-domke, 2018-10-12:
Sounds good. I'll upload a signed archive on Github/files.13-37.org for future releases. (0.3.0 coming very soon)

Probably one could also trust the archive created by Github: https://github.com/13-37-org/infnoise/archive/0.2.6.zip

But I prefer signing them separately. This will make the whole build process more transparent (also for the other distros).

AidanGG, 2018-10-12:
In that case I will probably hold off on publishing the `infnoise` stable package on the AUR until 0.3.0.

AidanGG, 2018-11-03:
I have added an entry to the AUR for the stable 0.3.0 release. To summarise, there are two packages:

[infnoise](https://aur.archlinux.org/packages/infnoise/): which builds from the latest stable release, using the signed source tarballs,
[infnoise-git](https://aur.archlinux.org/packages/infnoise-git/): which builds from the latest commit on the [13-37 fork](https://github.com/13-37-org/infnoise).

Feedback is welcome.

manuel-domke, 2019-03-21:
Thanks for your support. I'll close this issue now.

Closed 2019-03-21.

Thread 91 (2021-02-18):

infinite loop of syslog "did not claim interface 0 before use" messages

gilbert-fernandes, 2021-02-18:
Ubuntu 20.04 LTS
Installed infnoise from the apt in version 0.3.1+dfsg-1 amd64

ID: 0, Manufacturer: 13-37.org, Description: Infinite Noise TRNG, Serial: 1337-XXXXXXXX

When launching infnoise in daemon mode :
gf@orion:~$ sudo infnoise --dev-random --daemon

The lapotp fans start running fast and the /var/log/syslog fills with hundred of the following lines per second in infinite loop until the process is killed :

```
Feb 18 21:16:03 orion kernel: [45949.551186] usb 3-4: usbfs: process 83592 (infnoise) did not claim interface 0 before use
Feb 18 21:16:03 orion kernel: [45949.551197] usb 3-4: usbfs: process 83592 (infnoise) did not claim interface 0 before use
Feb 18 21:16:03 orion kernel: [45949.551206] usb 3-4: usbfs: process 83592 (infnoise) did not claim interface 0 before use
Feb 18 21:16:03 orion kernel: [45949.551213] usb 3-4: usbfs: process 83592 (infnoise) did not claim interface 0 before use
Feb 18 21:16:03 orion kernel: [45949.551223] usb 3-4: usbfs: process 83592 (infnoise) did not claim interface 0 before use
Feb 18 21:16:03 orion kernel: [45949.551230] usb 3-4: usbfs: process 83592 (infnoise) did not claim interface 0 before use
Feb 18 21:16:03 orion kernel: [45949.551240] usb 3-4: usbfs: process 83592 (infnoise) did not claim interface 0 before use
Feb 18 21:16:03 orion kernel: [45949.551248] usb 3-4: usbfs: process 83592 (infnoise) did not claim interface 0 before use
Feb 18 21:16:03 orion kernel: [45949.551266] usb 3-4: usbfs: process 83592 (infnoise) did not claim interface 0 before use
Feb 18 21:16:03 orion kernel: [45949.551275] usb 3-4: usbfs: process 83592 (infnoise) did not claim interface 0 before use
```

After a minute this added 59650431 lines to my syslog
Adding about 6 Gb of logs...

Seems I am running the latest available version, installed through apt.
TRNG key brand new.

gilbert-fernandes, 2021-02-18:
Ok I think I should not be trying to start the infnoise in daemon mode manually.

Once the infnoise package is installed, a service is available
And it already starts the device in daemon mode and injects data into the system random pool :

```
gf@orion:~/Documents/infnoise/software$ systemctl status infnoise
● infnoise.service - Wayward Geek InfNoise TRNG driver
     Loaded: loaded (/lib/systemd/system/infnoise.service; enabled; vendor preset: enabled)
     Active: active (running) since Thu 2021-02-18 21:38:40 CET; 2s ago
       Docs: man:infnoise.service(8)
    Process: 84837 ExecStart=/usr/sbin/infnoise --dev-random --daemon --pidfile /var/run/infnoise.pid>
   Main PID: 84838 (infnoise)
      Tasks: 1 (limit: 18644)
     Memory: 652.0K
     CGroup: /system.slice/infnoise.service
             └─84838 /usr/sbin/infnoise --dev-random --daemon --pidfile /var/run/infnoise.pid
```

So Ubuntu 20.04 + apt package we have to use systemctl
And it all works fine...

Closed 2021-02-18.

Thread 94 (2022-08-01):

Wrong ftdi_set_bitmode() and ftdi_set_baudrate() ordering

trosenkranz, 2022-08-01:
Hi Bill,

while trying to understand how the InfiniteNoise driver works, I found that the ftdi_set_baudrate()-method in libftdi applies a factor of 4 to the set baudrate when bitbang-mode is enabled (cf. [libftdi-repository](http://developer.intra2net.com/git/?p=libftdi;a=blob;f=src/ftdi.c;h=0a7fb274dd927d45615bbd26c11e950155164e46;hb=HEAD#l1470)). So in my understanding the driver first has to call ftdi_set_bitmode() and then ftdi_set_baudrate().

Currently in the code first the [ftdi_set_baudrate()](https://github.com/waywardgeek/infnoise/blob/66075cc79988bc891d37058724839487db0d3216/software/libinfnoise.c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) and then the [ftdi_set_bitmode()-method](
https://github.com/waywardgeek/infnoise/blob/66075cc79988bc891d37058724839487db0d3216/software/libinfnoise.c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) is called.

Am I missing something?

Tobias

waywardgeek, 2022-08-02:
You're probably right.  I originally picked the baud rate experimentally,
finding a value that worked well, and I was looking at the big-bang toggle
rate, and did not worry about what the baud rate was set to.  The current
square waves from the FTDI chip are correct, but there may be a factor of 4
difference in the baud rate and what we see on the oscilloscope.

On Mon, Aug 1, 2022 at 3:19 PM Tobias Rosenkranz ***@***.***>
wrote:

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

trosenkranz, 2022-08-09:
So am I right to assume, that the clock rate for reading/writing is 30kHz? If yes, this issue can be closed.

Thanks

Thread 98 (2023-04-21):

Error trying to run infnoise output through dieharder on Ubuntu

JamesTimothyMeech, 2023-04-21:
When I try to run the infnoise output through dieharder on my Ubuntu 22.04 computer I get this error:

`$ sudo infnoise | dieharder -g 200 -a
Error: USB read failed
# stdin_input_raw(): Error: EOF
`

JamesTimothyMeech, 2023-04-21:
The backslash before # comes from me escaping the # to stop github rendering the rest of the line as a markdown title

manuel-domke, 2024-10-09:
When installing the Infinite Noise driver, it also creates a systemd service called infnoise (that feeds /dev/random),
which you need to stop before running the infnoise command manually.

Run
systemctl infnoise stop
to stop it

Or
systemctl disable infnoise
to completely disable it.

Only then you can use the "infnoise" command manually.
Otherwise the systemd service will be interrupted  and when it restarts, it will interrupt your manually invoked infnoise command (race-condition)

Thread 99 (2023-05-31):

Expired web server certs

readnotify, 2023-05-31:
Not a good look for a security-related product.

# wget -O 13-37.org-code.asc https://13-37.org/files/pubkey.gpg
--2023-05-31 07:41:35--  https://13-37.org/files/pubkey.gpg
Resolving 13-37.org (13-37.org)... 2a01:4f9:4b:11c8::2, 135.181.73.247
Connecting to 13-37.org (13-37.org)|2a01:4f9:4b:11c8::2|:443... connected.
ERROR: The certificate of ‘13-37.org’ is not trusted.
ERROR: The certificate of ‘13-37.org’ has expired.
The certificate has expired

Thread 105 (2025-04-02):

Question: Can additional noise be induced using the multiplier?

bmmcwhirt, 2025-04-02:
Is is possible and or feasible to add additional noise by creating a feedback using the multiplier flag?

ExecStart=/usr/local/sbin/infnoise --dev-random --daemon --pidfile /var/run/infnoise.pid --multiplier "$(dd if=/dev/urandom bs=512 count=1)" --serial {my device serial}

or possibly use a second TRNG to inject into the multiplier of the first?

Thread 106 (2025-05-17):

Udev rule + SystemD service broken - dev-infnoise.service is never created & mtp-probe tries to probe the USB device

trinitronx, 2025-05-17:
I've seemingly run into the same issue as #90 where the SystemD [`infnoise.service` fails waiting for the dependency on `dev-infnoise.device`][1].

As it turns out, the `udev` rule for creating the `/dev/infnoise` symlink on `usb` is missing `TAG+="systemd"`, so the SystemD `dev-infnoise.device` is never created.

Therefore, the symlink gets created but _SystemD does not treat it as a device_ so `infnoise.service` fails because it depends on that `.device` existing.

Also as we can see [in the logs, `mtp-probe` tries to probe the USB device][2], which while innocuous is not necessary because it is not a USB Media Transfer Protocol device.

~~_TODO_ <sup>_Note to self_</sup>: _Create Pull Request to fix these issues._~~
PR Created: #107

[1]: https://gist.github.com/trinitronx/a190f905b141d705e37501d812bf6fb6#file-systemctl-status-infnoise-log-L15-L17
[2]: https://gist.github.com/trinitronx/a190f905b141d705e37501d812bf6fb6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

Closed 2025-05-18.

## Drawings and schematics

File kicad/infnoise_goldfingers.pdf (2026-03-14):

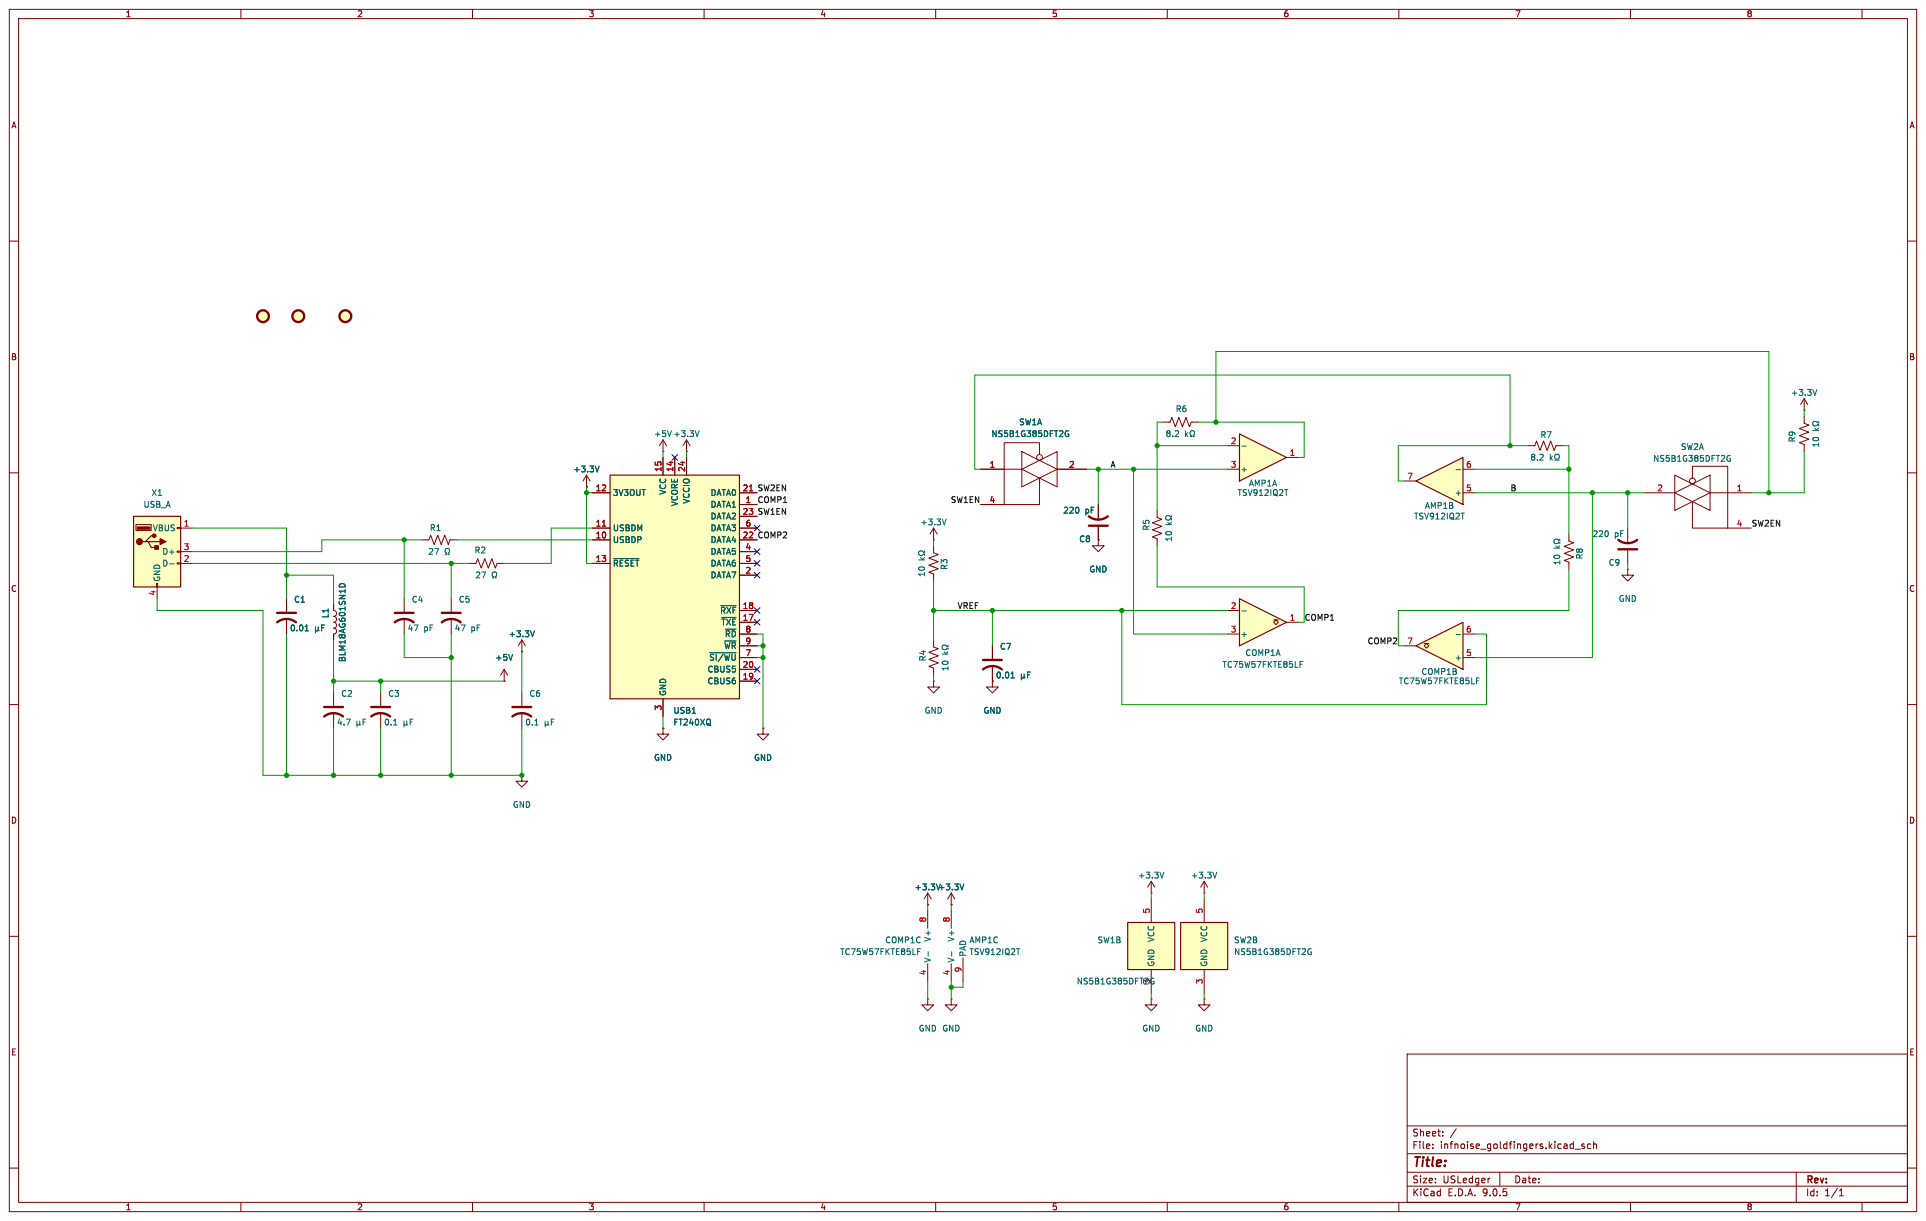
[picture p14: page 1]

3 VCORE 14 VCCIO 24 DATA0 21 DATA1 1 DATA2 23 DATA3 6 DATA4 22 DATA5 4 DATA6 5 DATA7 2 ~{RXF}18 ~{TXE}17 ~{RD}8 ~{WR}9 ~{SI/WU} 7 CBUS5 20 CBUS6 19 +3.3V

3 VCORE 14 VCCIO 24 DATA0 21 DATA1 1 DATA2 23 DATA3 6 DATA4 22 DATA5 4 DATA6 5 DATA7 2 ~{RXF}18 ~{TXE}17 ~{RD}8 ~{WR}9 ~{SI/WU} 7 CBUS5 20 CBUS6 19 USB1 FT240XQ V+

Id: 1/1 Title: File: infnoise_goldfingers.kicad_sch Sheet: /

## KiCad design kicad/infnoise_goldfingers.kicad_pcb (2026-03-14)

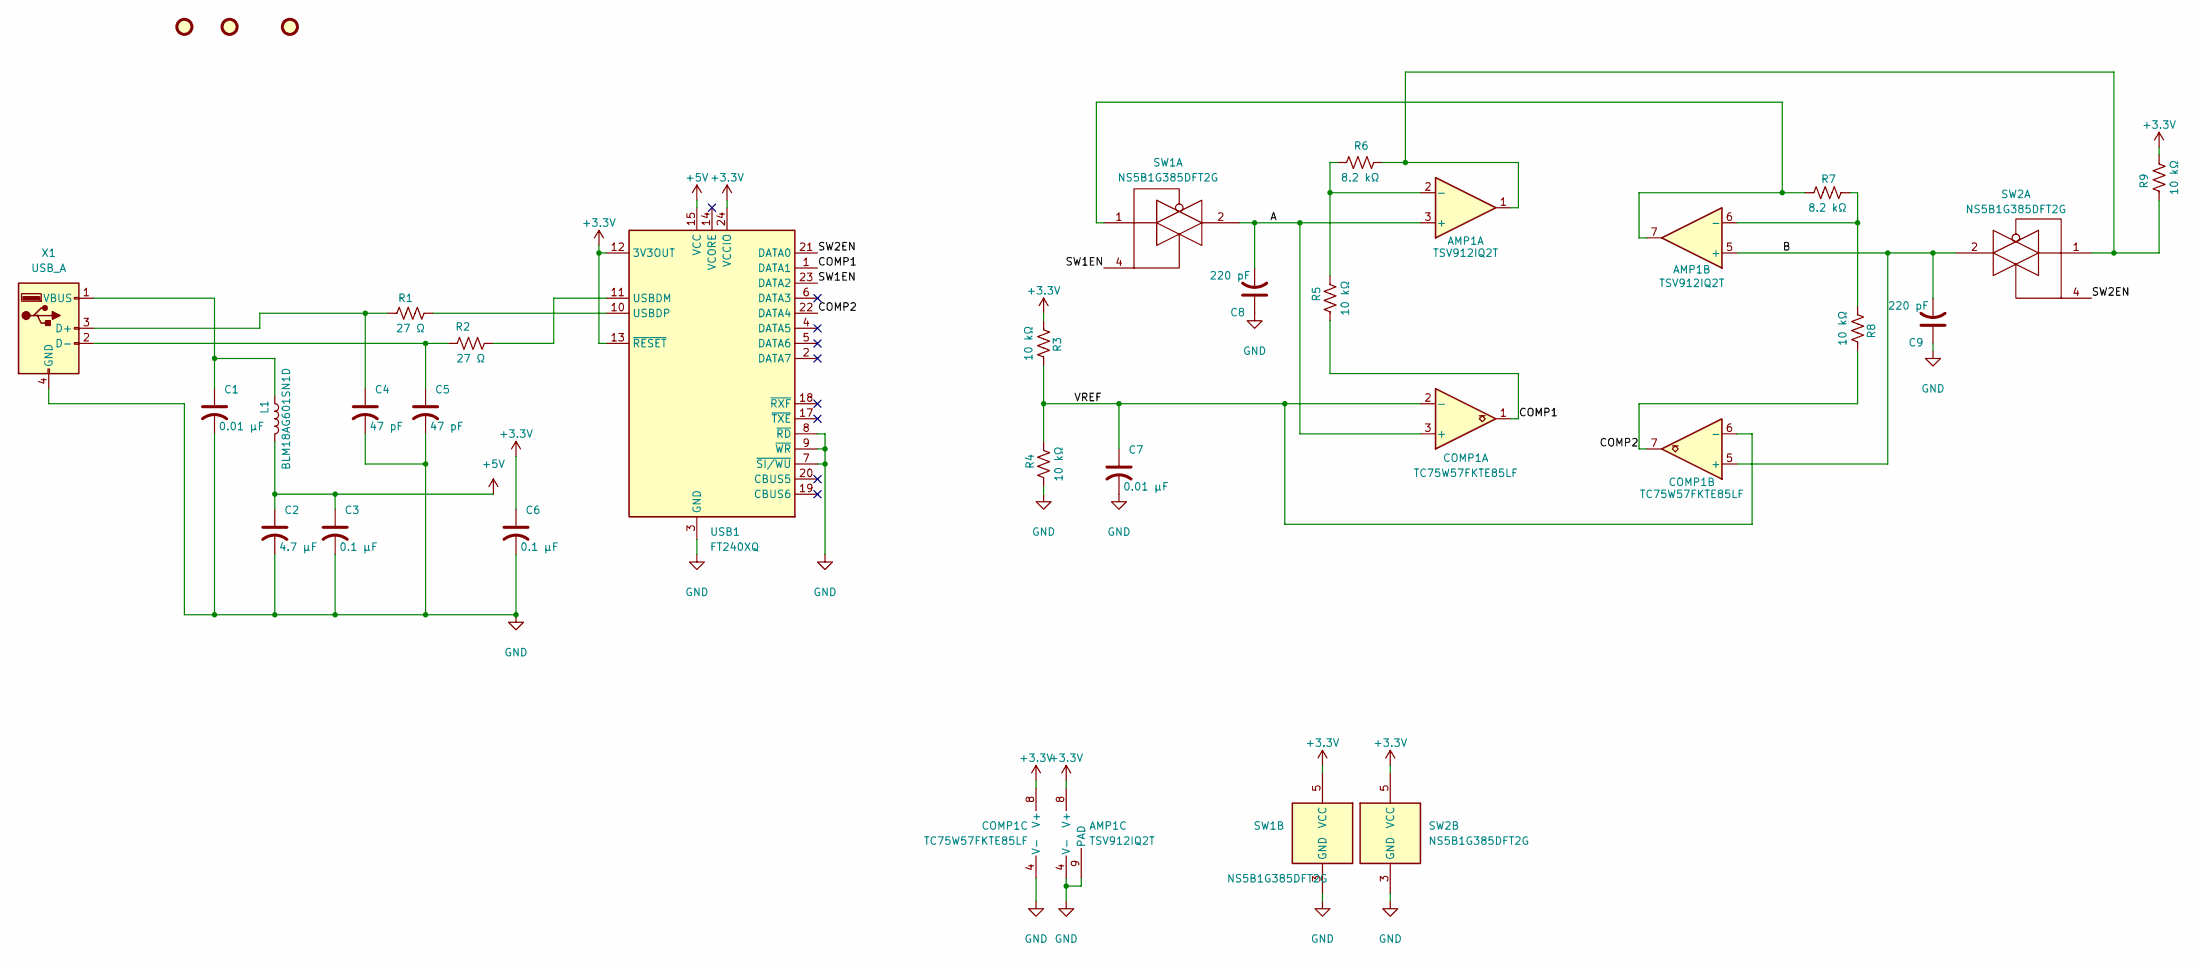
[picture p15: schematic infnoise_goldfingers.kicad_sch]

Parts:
AMP1: TSV912IQ2T; DFN-8-1EP_2x2mm_P0.5mm_EP1.05x1.75mm; MPN TSV912IQ2T; DigiKey SPN 497-12414-1-ND
C1, C7: 0.01 µF; C_0603_1608Metric; Part-DB Footprint 0603; digikey# 1276-1009-1-ND
C2: 4.7 µF; C_0603_1608Metric; Part-DB Footprint 0603; digikey# 1276-1784-1-ND
C3, C6: 0.1 µF; C_0603_1608Metric; Part-DB Footprint 0603; digikey# 1276-1000-1-ND
C4, C5: 47 pF; C_0603_1608Metric; Part-DB Footprint 0603; digikey# 1276-1037-1-ND
C8, C9: 220 pF; C_0603_1608Metric; Part-DB Footprint 0603; digikey# 1276-1048-1-ND
COMP1: TC75W57FKTE85LF; VSSOP-8_2.3x2mm_P0.5mm; MPN TC75W57FKTE85LF; DigiKey SPN TC75W57FKTE85LFCT-ND
FID1, FID2, FID3: FIDUCIALUFIDUCIAL; Fiducial_0.5mm_Mask1mm
L1: BLM18AG601SN1D; L_0603_1608Metric; MPN BLM18AG601SN1D; DigiKey SPN 490-1014-1-ND
R1, R2: 27 Ω; R_0603_1608Metric; Part-DB Footprint 0603; digikey# 311-27.0HRCT-ND
R3, R4, R5, R8, R9: 10 kΩ; R_0603_1608Metric; Part-DB Footprint 0603; digikey# 311-10.0KHRCT-ND
R6, R7: 8.2 kΩ; R_0603_1608Metric; Part-DB Footprint 0603; digikey# 311-8.20KHRCT-ND
SW1, SW2: NS5B1G385DFT2G; SOT-353_SC-70-5; MPN NS5B1G385DFT2G; DigiKey SPN NS5B1G385DFT2GOSCT-ND
USB1: FT240XQ; QFN-24-1EP_4x4mm_P0.5mm_EP2.6x2.6mm; MPN FT240XQ-R; DigiKey SPN 768-1126-1-ND
X1: USB_A; USB-A-RAWPINS

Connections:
+3.3V: AMP1.8 (V+), C6.1, COMP1.8 (V+), R3.1, R9.2, SW1.5 (VCC), SW2.5 (VCC), USB1.12 (3V3OUT), USB1.13 (~RESET), USB1.24 (VCCIO)
+5V: C2.1, C3.1, L1.2, USB1.15 (VCC)
/A: AMP1.3 (+), C8.2, COMP1.3 (+), SW1.2
/B: AMP1.5 (+), C9.2, COMP1.5 (+), SW2.2
/COMP1: COMP1.1, R5.1, USB1.1 (DATA1)
/COMP2: COMP1.7, R8.2, USB1.22 (DATA4)
/SW1EN: SW1.4, USB1.23 (DATA2)
/SW2EN: SW2.4, USB1.21 (DATA0)
/VREF: C7.1, COMP1.2 (-), COMP1.6 (-), R3.2, R4.2
GND: AMP1.4 (V-), AMP1.9 (PAD), C1.2, C2.2, C3.2, C4.2, C5.2, C6.2, C7.2, C8.1, C9.1, COMP1.4 (V-), R4.1, SW1.3 (GND), SW2.3 (GND), USB1.3 (GND), USB1.7 (~SI/WU), USB1.8 (~RD), USB1.9 (~WR), USB1.16 (GND), USB1.25 (GND), X1.4 (GND)
unnamed: AMP1.1, R6.2, R9.1, SW2.1
unnamed: AMP1.7, R7.1, SW1.1
unnamed: AMP1.2 (-), R5.2, R6.1
unnamed: AMP1.6 (-), R7.2, R8.1
unnamed: R2.2, USB1.11 (USBDM)
unnamed: R1.2, USB1.10 (USBDP)
unnamed: C4.1, R1.1, X1.3 (D+)
unnamed: C5.1, R2.1, X1.2 (D-)
unnamed: C1.1, L1.1, X1.1 (VBUS)

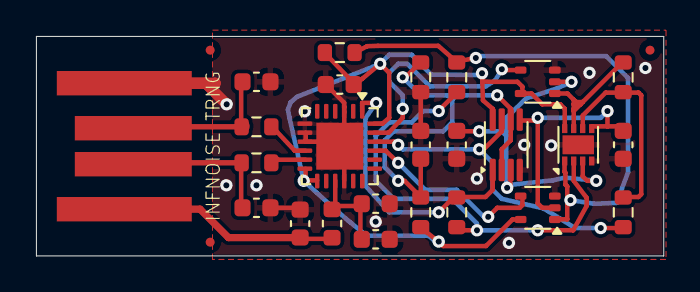
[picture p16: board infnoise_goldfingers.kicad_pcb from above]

Board: 2 copper layers, 34.8 x 12.2 mm, 28 parts (0 on the bottom side), 19 nets.

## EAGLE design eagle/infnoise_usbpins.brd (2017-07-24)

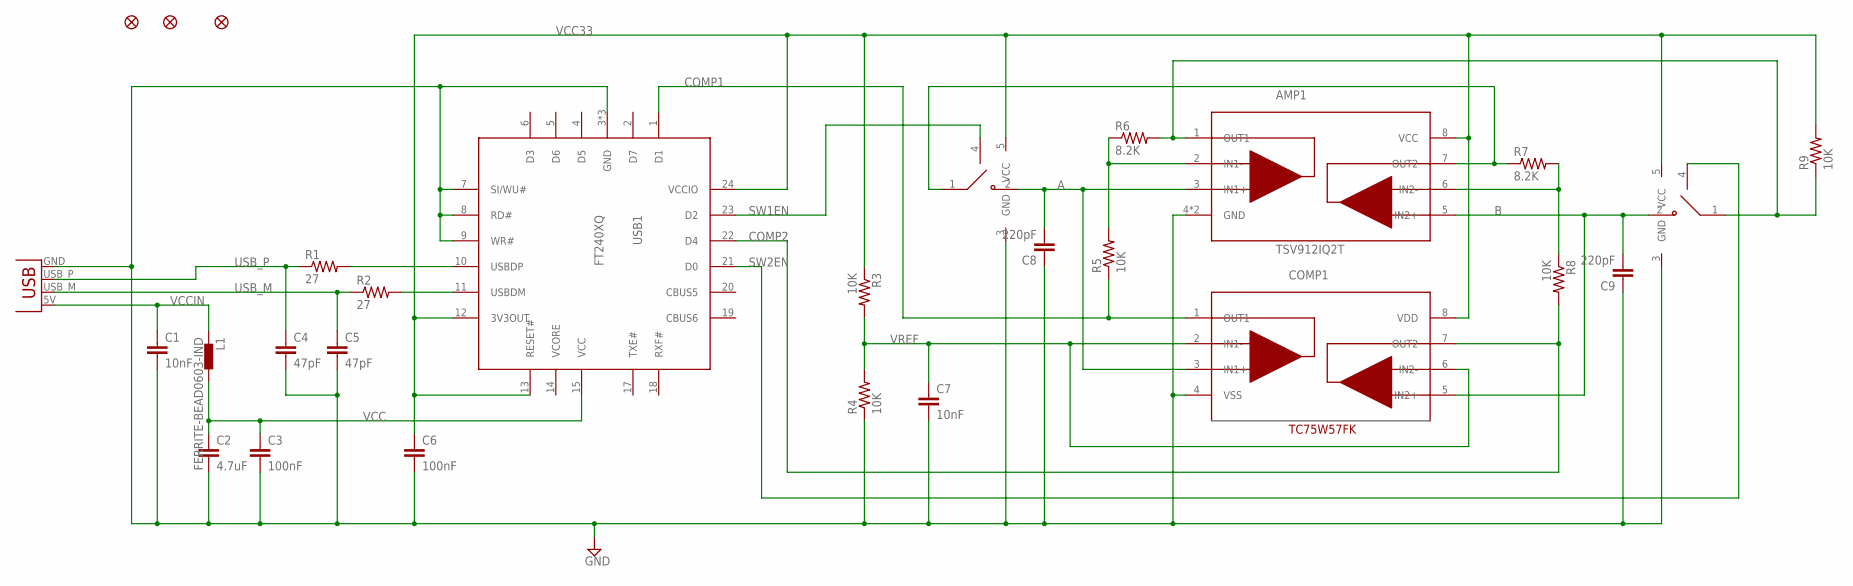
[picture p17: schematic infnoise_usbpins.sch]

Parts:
AMP1: TSV912IQ2T; DFN8-2X3
C1, C7: 10nF; 0603-CAP
C2: 4.7uF; 0603-CAP
C3, C6: 100nF; 0603-CAP
C4, C5: 47pF; 0603-CAP
C8, C9: 220pF; 0603-CAP
COMP1: TC75W57FK; SSOP8-P-0.50A
FID1, FID2, FID3: FIDUCIALUFIDUCIAL; MICRO-FIDUCIAL
L1: FERRITE-BEAD0603-IND; 0603-IND
R1, R2: 27; 0603-RES
R3, R4, R5, R8, R9: 10K; 0603-RES
R6, R7: 8.2K; 0603-RES
SW1, SW2: MC74VHC1G66DFT1G; SC70-5L
USB1: FT240XQ; QFN24-4X4
X1: USBRAWPINS; USB-A-RAWPINS

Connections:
A: AMP1.3 (IN1+), C8.2, COMP1.3 (IN1+), SW1.2 (NO)
AMP1OUT: AMP1.1 (OUT1), R6.2, R9.1, SW2.1 (COM)
AMP2OUT: AMP1.7 (OUT2), R7.1, SW1.1 (COM)
B: AMP1.5 (IN2+), C9.2, COMP1.5 (IN2+), SW2.2 (NO)
COMP1: COMP1.1 (OUT1), R5.1, USB1.1 (D1)
COMP2: COMP1.7 (OUT2), R8.2, USB1.22 (D4)
FB1: AMP1.2 (IN1-), R5.2, R6.1
FB2: AMP1.6 (IN2-), R7.2, R8.1
GND: AMP1.4 (GND), AMP1.EXP (GND), C1.2, C2.2, C3.2, C4.2, C5.2, C6.2, C7.2, C8.1, C9.1, COMP1.4 (VSS), R4.1, SW1.3 (GND), SW2.3 (GND), USB1.3 (GND), USB1.7 (SI/WU#), USB1.8 (RD#), USB1.9 (WR#), USB1.16 (GND), USB1.EXP (GND), X1.GND
unnamed: R1.2, USB1.10 (USBDP)
SW1EN: SW1.4 (IN), USB1.23 (D2)
SW2EN: SW2.4 (IN), USB1.21 (D0)
USBDM: R2.2, USB1.11 (USBDM)
USB_M: C5.1, R2.1, X1.USB_M (D-)
USB_P: C4.1, R1.1, X1.USB_P (D+)
VCC: C2.1, C3.1, L1.2, USB1.15 (VCC)
VCC33: AMP1.8 (VCC), C6.1, COMP1.8 (VDD), R3.1, R9.2, SW1.5 (VCC), SW2.5 (VCC), USB1.12 (3V3OUT), USB1.13 (RESET#), USB1.24 (VCCIO)
VCCIN: C1.1, L1.1, X1.5V (VCC)
VREF: C7.1, COMP1.2 (IN1-), COMP1.6 (IN2-), R3.2, R4.2

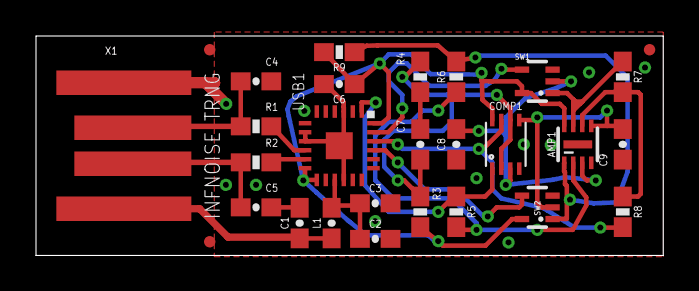
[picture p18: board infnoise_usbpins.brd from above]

Board: 2 copper layers, 34.8 x 12.2 mm, 28 parts (0 on the bottom side), 19 nets.

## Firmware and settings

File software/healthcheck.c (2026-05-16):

/*
Measure the entropy level dynamically from the Infinite Noise Multiplier.

The theory behind this is simple.  The next bit from the INM TRNG can be guessed, based on
the previous bits, by measuring how often a 0 or 1 occurs given the previous bits.  Update
these statistics dynamically, and use them to determine how hard it would be to predict
the current state.

For example, if 0100 is followed by 1 80% of the time, and we read a 1, the probability of
the input string being what it is decreases by multiplying it by 0.8.  If we read a 0, we
multiply the likelyhood of the current state by 0.2.

Because INMs generate about log(K)/log(2) bits per clock when K is the gain used in the
INM (between 1 and 2), we know how much entropy there should be coming from the device.
If the measured entropy diverges too strongly from the theoretical entropy, we should shut
down the entropy source, since it is not working correctly.

An assumption made is that bits far enough away are not correlated.  This is directly
confirmed.

*/

#include <stdio.h>
#include <stdlib.h>
#include <string.h>
#include <math.h>
#include <time.h>
#include "libinfnoise_private.h"

#define INM_MIN_DATA 80000u
#define INM_MIN_SAMPLE_SIZE 100u
#define INM_MAX_SEQUENCE 20u
#define INM_MAX_COUNT (1u << 14u)

// Print the tables of statistics.
void inmDumpStats(struct infnoise_health_state *hc) {
    uint32_t i;
    for(i = 0u; i < 1u << hc->N; i++) {
        printf("%x onesEven:%u zerosEven:%u onesOdd:%u zerosOdd:%u\n",
            i, hc->onesEven[i], hc->zerosEven[i], hc->onesOdd[i], hc->zerosOdd[i]);
    }
}

// Free memory used by the health check.
void inmHealthCheckStop(struct infnoise_health_state *hc) {
    if(hc->onesEven != NULL) {
        free(hc->onesEven);
        hc->onesEven = NULL;
    }
    if(hc->zerosEven != NULL) {
        free(hc->zerosEven);
        hc->zerosEven = NULL;
    }
    if(hc->onesOdd != NULL) {
        free(hc->onesOdd);
        hc->onesOdd = NULL;
    }
    if(hc->zerosOdd != NULL) {
        free(hc->zerosOdd);
        hc->zerosOdd = NULL;
    }
}

// Reset the statistics.
static void resetStats(struct infnoise_health_state *hc) {
    hc->numBitsSampled = 0u;
    hc->currentProbability = 1.0;
    hc->numBitsOfEntropy = 0u;
    hc->entropyLevel = 0u;
    hc->totalOnes = 0u;
    hc->totalZeros = 0u;
    hc->evenMisfires = 0u;
    hc->oddMisfires = 0u;
}

// Initialize the health check.  N is the number of bits used to predict the next bit.
// At least 8 bits must be used, and no more than 30.  In general, we should use bits
// large enough so that INM output will be uncorrelated with bits N samples back in time.
bool inmHealthCheckStart(struct infnoise_health_state *hc, uint8_t N, double K, bool debug) {
    if(N < 1u || N > 30u) {
        return false;
    }
    hc->debug = debug;
    hc->numBitsOfEntropy = 0u;
    hc->currentProbability = 1.0;
    hc->K = K;
    hc->N = N;
    hc->prevBits = 0u;
    hc->onesEven = calloc((size_t)1u << N, sizeof(*hc->onesEven));
    hc->zerosEven = calloc((size_t)1u << N, sizeof(*hc->zerosEven));
    hc->onesOdd = calloc((size_t)1u << N, sizeof(*hc->onesOdd));
    hc->zerosOdd = calloc((size_t)1u << N, sizeof(*hc->zerosOdd));
    hc->expectedEntropyPerBit = log(K)/log(2.0);
    hc->totalBits = 0u;
    hc->prevBit = false;
    hc->numSequentialZeros = 0u;
    hc->numSequentialOnes = 0u;
    resetStats(hc);
    if(hc->onesEven == NULL || hc->zerosEven == NULL || hc->onesOdd == NULL || hc->zerosOdd == NULL) {
        inmHealthCheckStop(hc);
        return false;
    }
    return true;
}

// If running continuously, it is possible to start overflowing the 32-bit counters for
// zeros and ones.  Check for this, and scale the stats if needed.
static void scaleStats(struct infnoise_health_state *hc) {
    uint32_t i;
    for(i = 0u; i < (1u << hc->N); i++) {
        hc->zerosEven[i] >>= 1u;
        hc->onesEven[i] >>= 1u;
        hc->zerosOdd[i] >>= 1u;
        hc->onesOdd[i] >>= 1u;
    }
}

// If running continuously, it is possible to start overflowing the 32-bit counters for
// zeros and ones.  Check for this, and scale the stats if needed.
static void scaleEntropy(struct infnoise_health_state *hc) {
    if(hc->numBitsSampled == INM_MIN_DATA) {
        hc->numBitsOfEntropy >>= 1u;
        hc->numBitsSampled >>= 1u;
        hc->evenMisfires >>= 1u;
        hc->oddMisfires >>= 1u;
    }
}

// If running continuously, it is possible to start overflowing the 32-bit counters for
// zeros and ones.  Check for this, and scale the stats if needed.
static void scaleZeroOneCounts(struct infnoise_health_state *hc) {
    uint64_t maxVal = hc->totalZeros >= hc->totalOnes? hc->totalZeros : hc->totalOnes;
    if(maxVal == INM_MIN_DATA) {
        hc->totalZeros >>= 1u;
        hc->totalOnes >>= 1u;
    }
}

// This should be called for each bit generated.
bool inmHealthCheckAddBit(struct infnoise_health_state *hc, bool evenBit, bool oddBit, bool even) {
    bool bit;
    if(even) {
        bit = evenBit;
        hc->evenMisfires += (evenBit != hc->prevEven);
    } else {
        bit = oddBit;
        hc->oddMisfires += (oddBit != hc->prevOdd);
    }
    hc->prevEven = evenBit;
    hc->prevOdd = oddBit;
    hc->totalBits++;
    if(hc->debug && (hc->totalBits & 0xfffffllu) == 0u) {
        fprintf(stderr, "Generated %llu bits.  %s to use data.  Estimated entropy per bit: %f, estimated K: %f\n",
            (long long)hc->totalBits, inmHealthCheckOkToUseData(hc)? "OK" : "NOT OK", inmHealthCheckEstimateEntropyPerBit(hc),
            inmHealthCheckEstimateK(hc));
        fprintf(stderr, "num1s:%f%%, even misfires:%f%%, odd misfires:%f%%\n",
            hc->totalOnes*100.0/(hc->totalZeros + hc->totalOnes),
            hc->evenMisfires*100.0/hc->numBitsSampled, hc->oddMisfires*100.0/hc->numBitsSampled);
        fflush(stderr);
    }
    hc->prevBits = (hc->prevBits << 1) & ((1 << hc->N)-1);
    if(hc->prevBit) {
        hc->prevBits |= 1;
    }
    hc->prevBit = bit;
    if(hc->numBitsSampled > 100u) {
        if(bit) {
            hc->totalOnes++;
            hc->numSequentialOnes++;
            hc->numSequentialZeros = 0u;
            if(hc->numSequentialOnes > INM_MAX_SEQUENCE) {
                fprintf(stderr, "Maximum sequence of %d 1's exceeded\n", INM_MAX_SEQUENCE);
                hc->numSequentialOnes = 0u;
                return false;
            }
        } else {
            hc->totalZeros++;
            hc->numSequentialZeros++;
            hc->numSequentialOnes = 0u;
            if(hc->numSequentialZeros > INM_MAX_SEQUENCE) {
                fprintf(stderr, "Maximum sequence of %d 0's exceeded\n", INM_MAX_SEQUENCE);
                hc->numSequentialZeros = 0u;
                return false;
            }
        }
    }
    uint32_t zeros, ones;
    if(even) {
        zeros = hc->zerosEven[hc->prevBits];
        ones = hc->onesEven[hc->prevBits];
    } else {
        zeros = hc->zerosOdd[hc->prevBits];
        ones = hc->onesOdd[hc->prevBits];
    }
    uint32_t total = zeros + ones;
    if(bit) {
        if(ones != 0u) {
            hc->currentProbability *= (double)ones/total;
        }
    } else {
        if(zeros != 0u) {
            hc->currentProbability *= (double)zeros/total;
        }
    }
    while(hc->currentProbability <= 0.5) {
        hc->currentProbability *= 2.0;
        hc->numBitsOfEntropy++;
        if(inmHealthCheckOkToUseData(hc)) {
            hc->entropyLevel++;
        }
    }
    //printf("probability:%f\n", hc->currentProbability);
    hc->numBitsSampled++;
    if(bit) {
        if(even) {
            hc->onesEven[hc->prevBits]++;
            if(hc->onesEven[hc->prevBits] == INM_MAX_COUNT) {
                scaleStats(hc);
            }
        } else {
            hc->onesOdd[hc->prevBits]++;
            if(hc->onesOdd[hc->prevBits] == INM_MAX_COUNT) {
                scaleStats(hc);
            }
        }
    } else {
        if(even) {
            hc->zerosEven[hc->prevBits]++;
            if(hc->zerosEven[hc->prevBits] == INM_MAX_COUNT) {
                scaleStats(hc);
            }
        } else {
            hc->zerosOdd[hc->prevBits]++;
            if(hc->zerosOdd[hc->prevBits] == INM_MAX_COUNT) {
                scaleStats(hc);
            }
        }
    }
    scaleEntropy(hc);
    scaleZeroOneCounts(hc);
    return true;
}

// Once we have enough samples, we know that entropyPerBit = log(K)/log(2), so
// K must be 2^entryopPerBit.
double inmHealthCheckEstimateK(struct infnoise_health_state *hc) {
    double entropyPerBit = (double)hc->numBitsOfEntropy/hc->numBitsSampled;
    return pow(2.0, entropyPerBit);
}

// Once we have enough samples, we know that entropyPerBit = log(K)/log(2), so
// K must be 2^entryopPerBit.
double inmHealthCheckEstimateEntropyPerBit(struct infnoise_health_state *hc) {
    return (double)hc->numBitsOfEntropy/hc->numBitsSampled;
}

// Return true if the health checker has enough data to verify proper operation of the INM.
bool inmHealthCheckOkToUseData(struct infnoise_health_state *hc) {
    double entropy = inmHealthCheckEstimateEntropyPerBit(hc);
    return hc->totalBits >= INM_MIN_DATA && entropy*INM_ACCURACY >= hc->expectedEntropyPerBit &&
        entropy/INM_ACCURACY <= hc->expectedEntropyPerBit;
}

// Just return the entropy level added so far in bytes;
uint32_t inmGetEntropyLevel(struct infnoise_health_state *hc) {
    return hc->entropyLevel;
}

// Reduce the entropy level by numBytes.
void inmClearEntropyLevel(struct infnoise_health_state *hc) {
    hc->entropyLevel = 0u;
}

// Check that the entropy of the last group of bits was high enough for use.
bool inmEntropyOnTarget(struct infnoise_health_state *hc, uint32_t entropy, uint32_t numBits) {
    uint32_t expectedEntropy = (uint32_t)(numBits*hc->expectedEntropyPerBit);
    return expectedEntropy < entropy*INM_ACCURACY;
}

#ifdef TEST_HEALTHCHECK
#include "infnoise.h"

// Compare the ability to predict with 1 fewer bits and see how much less accurate we are.
static void checkLSBStatsForNBits(struct infnoise_health_state *hc, uint8_t N) {
    uint32_t i, j;
    uint32_t totalGuesses = 0u;
    uint32_t totalRight = 0.0;
    for(i = 0u; i < (1u << N); i++) {
        uint32_t zeros = 0u;
        uint32_t ones = 0u;
        for(j = 0u; j < (1u << (hc->N - N)); j++) {
            uint32_t pos = i + j*(1u << N);
            zeros += hc->zerosEven[pos];
            ones += hc->onesEven[pos];
        }
        if(zeros >= ones) {
            totalRight += zeros;
        } else {
            totalRight += ones;
        }
        totalGuesses += zeros + ones;
    }
    printf("Probability of guessing correctly with %u bits: %f\n", N, (double)totalRight/totalGuesses);
}

// Compare the ability to predict with 1 fewer bits and see how much less accurate we are.
static void checkLSBStats(struct infnoise_health_state *hc) {
    uint32_t N;
    for(N = 1u; N <= hc->N; N++) {
        checkLSBStatsForNBits(hc, N);
    }
}

/* This could be built with one opamp for the multiplier, a comparator with
   rail-to-rail outputs, and switches and caps and resistors.*/
static inline bool updateA(double *A, double K, double noise) {
    if(*A > 1.0) {
        *A = 1.0;
    } else if (*A < 0.0) {
        *A = 0.0;
    }
    *A += noise;
    if(*A > 0.5) {
        *A = K**A - (K-1);
        return true;
    }
    *A += noise;
    *A = K**A;
    return false;
}

static inline bool computeRandBit(double *A, double K, double noiseAmplitude) {
    double noise = noiseAmplitude*(((double)rand()/RAND_MAX) - 0.5);
    return updateA(A, K, noise);
}

static void initOpts(struct opt_struct *opts) {
    opts->outputMultiplier = 0u;
    opts->daemon =
        opts->debug =
        opts->devRandom =
        opts->noOutput =
        opts->listDevices =
        opts->raw = false;
    opts->version = false;
    opts->help = false;
    opts->none = false;
    opts->pidFileName =
        opts->serial = NULL;
}

int main() {
    struct opt_struct opts;
    initOpts(&opts);
    //double K = sqrt(2.0);
    double K = 1.82;
    uint8_t N = 16u;
    struct infnoise_health_state hc;
    memset(&hc, 0, sizeof(hc));
    inmHealthCheckStart(&hc, N, K, false);
    srand(time(NULL));
    double A = (double)rand()/RAND_MAX; // Simulating INM
    double noiseAmplitude = 1.0/(1u << 10);
    uint32_t i;

    for(i = 0u; i < 32u; i++) {
        // Throw away some initial bits.
        computeRandBit(&A, K, noiseAmplitude);
    }
    bool evenBit = false;
    bool oddBit = false;
    for(i = 0u; i < 1u << 28u; i++) {
        bool bit = computeRandBit(&A, K, noiseAmplitude);
        bool even = !(i & 1);
        if(even) {
            evenBit = bit;
        } else {
            oddBit = bit;
        }
        if(!inmHealthCheckAddBit(&hc, evenBit, oddBit, even)) {
            fprintf(stderr, "Failed health check!\n");
            return 1;
        }
        if(hc.totalBits > 0u && (hc.totalBits & 0xfffffff) == 0) {
            printf("Estimated entropy per bit: %f, estimated K: %f\n", inmHealthCheckEstimateEntropyPerBit(&hc),
                inmHealthCheckEstimateK(&hc));
            checkLSBStats(&hc);
        }
    }
    inmDumpStats(&hc);
    inmHealthCheckStop(&hc);
    return 0;
}
#endif

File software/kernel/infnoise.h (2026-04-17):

/* SPDX-License-Identifier: GPL-2.0-or-later */
/*
 * Infinite Noise TRNG kernel driver
 *
 * Copyright (C) 2024 Manuel Domke
 *
 * Based on the userspace driver by Bill Cox
 * Hardware design by Bill Cox
 */

#ifndef INFNOISE_H
#define INFNOISE_H

#include <linux/types.h>
#include <linux/usb.h>
#include <linux/hw_random.h>
#include <linux/mutex.h>
#include <linux/completion.h>
#include <linux/workqueue.h>

/* USB device IDs - Infinite Noise TRNG (pid.codes registered) */
#define INFNOISE_VENDOR_ID	0x1209	/* pid.codes VID */
#define INFNOISE_PRODUCT_ID	0x3701	/* Infinite Noise PID */

/* FTDI commands (SIO requests) */
#define FTDI_SIO_RESET			0x00
#define FTDI_SIO_SET_MODEM_CTRL		0x01
#define FTDI_SIO_SET_FLOW_CTRL		0x02
#define FTDI_SIO_SET_BAUDRATE		0x03
#define FTDI_SIO_SET_DATA		0x04
#define FTDI_SIO_GET_MODEM_STATUS	0x05
#define FTDI_SIO_SET_EVENT_CHAR		0x06
#define FTDI_SIO_SET_ERROR_CHAR		0x07
#define FTDI_SIO_SET_LATENCY_TIMER	0x09
#define FTDI_SIO_GET_LATENCY_TIMER	0x0A
#define FTDI_SIO_SET_BITMODE		0x0B
#define FTDI_SIO_READ_PINS		0x0C
#define FTDI_SIO_READ_EEPROM		0x90
#define FTDI_SIO_WRITE_EEPROM		0x91

/* FTDI reset commands */
#define FTDI_SIO_RESET_SIO		0x00
#define FTDI_SIO_RESET_PURGE_RX		0x01
#define FTDI_SIO_RESET_PURGE_TX		0x02

/* FTDI bit-bang modes */
#define FTDI_BITMODE_RESET		0x00
#define FTDI_BITMODE_BITBANG		0x01
#define FTDI_BITMODE_MPSSE		0x02
#define FTDI_BITMODE_SYNCBB		0x04	/* Synchronous bit-bang */
#define FTDI_BITMODE_MCU		0x08
#define FTDI_BITMODE_OPTO		0x10
#define FTDI_BITMODE_CBUS		0x20
#define FTDI_BITMODE_SYNCFF		0x40

/* Pin definitions for FT240X */
#define INFNOISE_COMP1		1	/* Comparator 1 input */
#define INFNOISE_COMP2		4	/* Comparator 2 input */
#define INFNOISE_SWEN1		2	/* Switch enable 1 output */
#define INFNOISE_SWEN2		0	/* Switch enable 2 output */

/* Address/debug pins */
#define INFNOISE_ADDR0		3
#define INFNOISE_ADDR1		5
#define INFNOISE_ADDR2		6
#define INFNOISE_ADDR3		7

/* Output mask: all pins except COMP1 and COMP2 are outputs */
#define INFNOISE_MASK		(0xFF & ~(1 << INFNOISE_COMP1) & ~(1 << INFNOISE_COMP2))

/* FTDI interface index (1-based: interface 0 uses index 1) */
#define FTDI_INDEX_INTERFACE_A	1

/* Buffer sizes */
#define INFNOISE_BUFLEN		512	/* FT240X buffer size, must be multiple of 64 */
#define INFNOISE_BYTES_OUT	(INFNOISE_BUFLEN / 8)	/* 64 bytes extracted */

/* FTDI packet format: each 64-byte USB packet has 2 status bytes + 62 data bytes */
#define FTDI_PACKET_SIZE	64
#define FTDI_STATUS_SIZE	2
#define FTDI_DATA_PER_PACKET	(FTDI_PACKET_SIZE - FTDI_STATUS_SIZE)  /* 62 */
/* For 512 bytes of data, we need ceil(512/62) = 9 packets = 576 bytes */
#define INFNOISE_USB_READ_SIZE	(((INFNOISE_BUFLEN + FTDI_DATA_PER_PACKET - 1) / FTDI_DATA_PER_PACKET) * FTDI_PACKET_SIZE)

/* Health check constants */
#define INM_PREDICTION_BITS	14	/* Bits used for prediction */
#define INM_TABLE_SIZE		(1 << INM_PREDICTION_BITS)	/* 16384 entries */
#define INM_MIN_DATA		80000	/* Minimum bits before data is valid */
#define INM_MIN_SAMPLE_SIZE	100	/* Minimum samples */
#define INM_MAX_SEQUENCE	20	/* Max consecutive same bits */
#define INM_MAX_COUNT		(1 << 14)	/* Max counter value before scaling */

/*
 * Fixed-point arithmetic for health check (avoid floating point in kernel)
 * Using 16.16 fixed point format
 */
#define FP_SHIFT		16
#define FP_ONE			(1 << FP_SHIFT)	/* 1.0 in fixed point */
#define FP_HALF			(FP_ONE >> 1)	/* 0.5 in fixed point */

/* Design constants in fixed-point (K = 1.84) */
#define INM_DESIGN_K_FP		120586	/* 1.84 * 65536 */
/* log2(1.84) ≈ 0.88 in fixed-point */
#define INM_EXPECTED_ENTROPY_FP	57671	/* 0.88 * 65536 */
/* INM_ACCURACY = 1.03 in fixed-point */
#define INM_ACCURACY_FP		67502	/* 1.03 * 65536 */

/* Keccak-1600 constants */
#define KECCAK_STATE_SIZE	200	/* 1600 bits = 200 bytes */
#define KECCAK_LANES		25	/* 5x5 lanes */
#define KECCAK_ROUNDS		24	/* Number of rounds */

/*
 * hwrng quality settings (bits of entropy per 1024 bits of input)
 * - Raw mode: 0.88 bits/bit (unwhitened, reflects true entropy rate)
 * - Whitened mode: ~1.0 bits/bit (Keccak output is cryptographically uniform)
 */
#define INFNOISE_QUALITY_RAW		880	/* Raw: 0.88 bits/bit */
#define INFNOISE_QUALITY_WHITENED	990	/* Whitened: ~1.0 bits/bit, slight margin */

/* Timeouts */
#define INFNOISE_USB_TIMEOUT	1000	/* USB timeout in ms */
#define INFNOISE_WARMUP_ROUNDS	5000	/* Max warmup rounds */

/* Error recovery */
#define INFNOISE_MAX_RETRIES		3	/* Retries per transfer */
#define INFNOISE_RECOVERY_THRESHOLD	5	/* Consecutive errors before recovery */
#define INFNOISE_RETRY_DELAY_MS		10	/* Delay between retries */

/* Module parameters */
extern bool infnoise_debug;
extern bool infnoise_raw_mode;

/* IOCTL definitions */
#define INFNOISE_IOC_MAGIC	'N'
#define INFNOISE_GET_STATS	_IOR(INFNOISE_IOC_MAGIC, 1, struct infnoise_stats)
#define INFNOISE_SET_RAW	_IOW(INFNOISE_IOC_MAGIC, 2, int)
#define INFNOISE_GET_ENTROPY	_IOR(INFNOISE_IOC_MAGIC, 3, u32)

/*
 * Statistics structure for ioctl (UAPI)
 *
 * Layout must be identical on 32-bit and 64-bit so that a 32-bit
 * userspace process can issue INFNOISE_GET_STATS on a 64-bit kernel.
 * Explicit padding ensures sizeof() == 40 on both, and __aligned(8)
 * forces u64 alignment on 32-bit where u64 is normally 4-byte aligned.
 */
struct infnoise_stats {
	__u64 total_bits;
	__u32 total_ones;
	__u32 total_zeros;
	__u32 even_misfires;
	__u32 odd_misfires;
	__u32 entropy_estimate;	/* Fixed-point 16.16 */
	__u32 k_estimate;	/* Fixed-point 16.16 */
	__u8 warmup_complete;
	__u8 health_ok;
	__u8 __pad[6];
} __aligned(8);

/* Health check state */
struct infnoise_health {
	u32 *ones_even;		/* Prediction table for even bits = 1 */
	u32 *zeros_even;	/* Prediction table for even bits = 0 */
	u32 *ones_odd;		/* Prediction table for odd bits = 1 */
	u32 *zeros_odd;		/* Prediction table for odd bits = 0 */

	u32 prev_bits;		/* Previous N bits for prediction */
	u32 num_bits_sampled;	/* Total bits in current entropy window */
	u32 num_bits_of_entropy;/* Estimated entropy bits */
	u32 entropy_level;	/* Accumulated entropy */

	u64 total_bits;		/* Total bits processed */
	u32 total_ones;		/* Count of 1 bits */
	u32 total_zeros;	/* Count of 0 bits */

	u32 even_misfires;	/* Even bit prediction failures */
	u32 odd_misfires;	/* Odd bit prediction failures */

	u32 seq_zeros;		/* Consecutive zeros */
	u32 seq_ones;		/* Consecutive ones */

	u32 current_prob;	/* Current probability (fixed-point) */

	bool prev_bit;		/* Previous bit value */
	bool prev_even;		/* Previous even bit */
	bool prev_odd;		/* Previous odd bit */
	bool ok_to_use;		/* Health check passed */
};

/* Keccak state */
struct infnoise_keccak {
	u8 state[KECCAK_STATE_SIZE];
};
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

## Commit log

2014-09-29 Switched to using OPA4354 quad op-amp for improved performance
2014-09-29 Working on BOM
    [BOM.ods]
2014-10-07 partlist work
    [BOM.ods]
2014-10-10 Added eagle files
    [BOM.ods, infnoise.brd, infnoise.sch]
2014-10-10 Added bitmap of board to README
    [infnoise.brd]
2014-10-10 minor cleanup
    [infnoise.brd, infnoise.sch]
2014-10-10 Increased widths and spacing based on advice on web
    [infnoise.brd, infnoise.sch]
2014-10-11 Updated part list
    [BOM.ods]
2014-10-12 Changed to real USB connector
    [infnoise.brd, infnoise.sch]
2014-10-12 Updated to not extend outside board boundary
    [infnoise.brd, infnoise.sch]
2014-10-13 Modified board to fit USB stick enclosure
    [BOM.ods, infnoise.brd, infnoise.sch]
2014-10-13 README update
    [BOM.ods]
2014-10-15 Converted to 0603 parts to be compatible with Small Batch Assembly
    [BOM.ods, infnoise.brd, infnoise.sch]
2014-10-15 move a wire
    [infnoise.brd]
2014-10-16 Updated driver to use correct pins
    [infnoise.brd, infnoise.sch]
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2014-10-20 Updates to board based on fixes to breadboard
    [BOM.ods, infnoise.brd, infnoise.sch]
2014-10-21 minor board update
    [infnoise.brd]
2014-10-23 Changed 100pF caps to 220pF
    [BOM.ods, infnoise.brd, infnoise.sch]
2014-10-26 Got the V1 version of the INM board working
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2014-10-28 Tightened the bounds on acceptable entropy generation to be no more than 2% over or under predected entropy
    [healthcheck.c]
2014-11-02 Modified board to remove resistor in feedback, as well as pull-down
    [infnoise.brd, infnoise.sch]
2014-11-02 Switched to a USB connector designed for 1.6mm thick boards
    [BOM.ods]
2014-11-03 Updated BOM
    [BOM.ods, infnoise.brd, infnoise.sch]
2014-11-07 Library tweaks (non-structural)
    I've adjusted the library as follows:
    Changed text alignment (centered, mostly) on parts, made positioning
    more consistent.
    Reduced tKeepout as it was a rather on the generous side for the 0402
    and 0403 parts.
    Added / fixed a few Device descriptions.
2014-11-07 Board clean-up, parts updated from modified library
    Schematic:
    - Only updated parts from the modified library
    Board:
    - Moved parts, vias, onto mm grid (was arbitrary?)
    - Major re-tracing to keep traces on-grid
    - Added full board ground planes (both sides) with grounding vias
    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
    [infnoise.brd, infnoise.sch]
2014-11-08 Board layout changed
    I moved the components on the board around to give a better visual
    representation of the components of the infnoise; USB protection,
    filter, divider network, and then where the actual magic happens. Vias
    galore, but ERC and DRC satisfied.
    [infnoise.brd, infnoise.sch]
2014-11-08 Added timer to insure I/O operations are fast enough for bit-bang
2014-11-12 Added Microsoft compatible version of BOM spreadsheet
    [BOM.xlsx]
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2014-11-14 Added BOM-81.ods
    [BOM-81.ods]
2014-11-14 renamed BOM-81 to BOM-80
    [BOM-80.ods]
2014-11-14 Added 3 fiducial marks on the board
    [infnoise.brd, infnoise.sch]
2014-11-17 Added generated files for SmallBatchAssembly
    [infnoise_SBA_BOM.csv]
2014-11-17 Working on edge-connector hack version
    [infnoise_edgecon.brd, infnoise_edgecon.sch]
2014-11-22 Updated README to use modular noise multiplier
    [infnoise_edgecon.brd, infnoise_edgecon.sch]
2014-11-22 Updated BOM for USPS business mailing pricing
    [BOM.ods]
2014-11-23 Cleaned up edge connector board a bit
    [infnoise_edgecon.brd]
2014-11-23 Tweaked edge connector hack board
    [infnoise_edgecon.brd]
2014-11-25 Changed architecture to modular entropy multiplier
    [BOM-80.ods]
2014-11-26 Made 0.5mm pads all the same size and shrank QFN24 center pad
    [infnoise.brd, infnoise.sch, infnoise_edgecon.brd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]
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2014-12-26 Added a hopefully improved edge connector hack where I can solder real USB pins to the board
    [infnoise_usbpins.brd, infnoise_usbpins.sch]
2015-03-07 Changed gain target to 1.84
    [infnoise_edgecon.brd, infnoise_usbpins.brd]
2015-03-07 minor board tweak
    [infnoise_usbpins.brd]
2015-06-25 Added a gold-finger version suitable for production at Advanced Circuits
    [infnoise_goldfingers.brd, infnoise_goldfingers.sch]
2015-08-23 fixing 0D error and broken win build
    [healthcheck.c, infnoise.h]
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2017-07-24 Changed bottom solder mask and text
    [infnoise_usbpins.brd]
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2017-08-30 updated readme
    added repos and link to releases
    updated udev rule
    new command line options --serial and --list-devices
2017-09-10 Fix compiler-warning from GCC 6.4
    Redefining #defines gives a warning. That is trated like an error
    with current compiler options.
2017-09-19 OpenRC script: Fix dependencies
    Wait for filesystems to be mounted. This makes sure there is a
    place to write the PID-file.
    Provide "trng" for other scripts to depend on.
2017-12-23 fixed stopping of service when device is unplugged
2017-12-23 improved error handling for listing devices and nicer output
2018-01-29 ported from EAGLE to KiCad
    [infnoise_goldfingers.kicad_pcb, infnoise_goldfingers.sch]
2018-01-29 update BOM with Mouser part numbers, as DigiKey no longer carries the TC75W57FK and some of the passives are also either gone or on their way out
    [bom.csv]
2018-02-17 ...and the substitutions I had made at Mouser for C4 & C5 were 0201, not 0603. Doh! BOM fixed.
    [bom.csv]
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2018-02-26 --help returns with exit-code 0 now. rc=1 when errors in option parsing.
    [infnoise.h]
2018-02-28 add 3D models
    [infnoise_goldfingers.kicad_pcb]
2018-03-01 finished assigning models to PCB
    [infnoise_goldfingers.kicad_pcb]
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2018-04-18 error messages / no (or less?) stderr in lib functions
    [libinfnoise_private.h]
2018-04-21 revert changed to listUSBDevices, for now it just print to stdout
    [libinfnoise_private.h]
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2018-04-22 new approach for error handling
    [libinfnoise_private.h]
2018-04-22 fix infnoise-tools build & libinfnoise
    [healthcheck.c]
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2018-06-24 Fix a couple of spelling errors
    This fixes errors in “initialize” and “outputting”, flagged by
    Debian’s Lintian tool.
2018-06-28 Fix to build infnoise on current ArchLinux
2018-06-28 Fix related to missing include
    [libinfnoise_private.h]
2018-06-28 Fix related to missing include (PATH_MAX)
    [infnoise.h]
2018-07-06 Mac error message on unable to open device. Clean target in Makefile, removed ldconfig for macos
2018-07-11 Quell git warnings about compiled files, make output of the --list-devices command more readable when we have multiple devices inserted.
2018-07-17 refactored outputBytes (/dev/random not working yet)
    [infnoise.h, libinfnoise_private.h]
2018-07-24 finish infnoise_context & start work on listUSBDevices (to return a device list struct)
2018-07-26 untested fix for --list-devices (no device at hand to test right now..)
2018-07-26 fix --list-devices (still buggy, but works!)
2018-07-27 fix --list-devices
2018-08-11 fix buffer size for multiplier mode
    [libinfnoise_private.h]
2018-08-27 next big step completed: fixed keccak multiplicator and --dev-random mode after libinfnoise refactoring (interface changed!)
    [libinfnoise_private.h]
2018-09-07 fix buffer size for raw mode & error handling when no device is connected
2019-03-21 In case fprintf() fails, still close the file descr.
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2019-03-24 Fix TEST_HEALTHCHECK as of typo
    [healthcheck.c]
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2019-03-31 Fix when no device available
2019-03-31 sprintf() in not a buffer, could create any issue
    [libinfnoise_private.h]
2020-04-15 Fix: in case all if-statements in processBytes were not taken, the routine needs to return 0, *bytesWritten has an old value, that is no more true
2023-02-11 fixed compiler warning:
    findlongest.c:101:28: error: argument 1 value ‘2147483648’ exceeds maximum object size 2147483647 [-Werror=alloc-size-larger-than=]
    101 | uint8_t *stringsSeen = calloc((uint64_t)1 << (MAX_STRING_SIZE-3u), sizeof(uint8_t));
    | ^~~~~~~~~~~~~~~~~~~~~~~~~~~~~~~~~~~~~~~~~~~~~~~~~~~~~~~~~~~~
2025-05-17 udev: Fix systemd tag for /dev/infnoise, mtp-probe, ModemManager: ignore
    - Fixes #106
    - Fixes #90
    - Fixes #93
2026-04-11 kmod: fix double-counting of bytes_generated
    infnoise_read_data() already increments dev->bytes_generated on every
    successful return path (lines 540, 568, 595). Both infnoise_hwrng_read()
    and infnoise_char_read() add a second increment after calling
    infnoise_read_data(), doubling the reported byte count.
    Remove the duplicate increments in the callers.
    Tested: built with VID/PID patched to 0x0403:0x6015 (stock FTDI) on
    kernel 6.18.21-1-lts with Infinite Noise TRNG hardware. 10/10 tests pass
    (see test_infnoise.c). VID/PID change is local-only for testing; the
    committed code retains 0x1209:0x3701 as upstream intended.
2026-04-12 kmod: fix busy-wait spin in infnoise_char_read on zero-length return
    When infnoise_read_data() returns 0 (health check not ready, entropy
    below target), the blocking read loop re-enters immediately with no
    sleep or schedule. This pins a CPU core and triggers soft lockup
    warnings under CONFIG_DETECT_SOFTLOCKUP.
    Add msleep(INFNOISE_RETRY_DELAY_MS) to back off between retries and
    check signal_pending() so the read is interruptible (Ctrl-C, kill).
    committe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
2026-04-12 kmod: add signal interruptibility regression test
    Adds test_interruptible() to the test harness: forks a child that
    reads from /dev/infnoise0 in a blocking loop, parent sends SIGUSR1
    after 500ms. Without the signal_pending() check in the retry loop,
    the child hangs forever.
2026-04-12 kmod: add compat_ioctl for 32-bit userspace on 64-bit kernels
    struct infnoise_stats contains a u64 followed by u32s and u8s. On
    64-bit kernels, u64 has 8-byte alignment and the struct is padded to
    40 bytes. On 32-bit, u64 has 4-byte alignment and padding yields 36
    bytes. The _IOR macro encodes sizeof() into the ioctl number, so a
    32-bit process gets a different ioctl number and copy_to_user copies
    the wrong size — returning garbage or triggering -ENOTTY.
    Fix:
    - Add explicit __pad[6] and __aligned(8) to infnoise_stats so the
    struct is 40 bytes with identical layout on both architectures.
    - Use __u64/__u32/__u8 types (UAPI-safe fixed-width types).
    - Zero the struct in infnoise_health_g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
    [infnoise.h]
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2026-04-21 eliminate global state: move all globals into infnoise_context
    Move 25 file-scope globals (2 in libinfnoise.c, 23 in healthcheck.c) into
    the per-device infnoise_context struct, enabling thread-safe multi-instance
    use of the library.
    New struct infnoise_health_state embedded in infnoise_context holds all
    health checker state (prediction tables, entropy counters, sequential bit
    trackers). Keccak sponge state and USB clock buffer also moved into context.
    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
2026-04-21 add error codes enum and signed readData return type
    Add infnoise_error_t enum with machine-readable error codes for all
    failure modes. Change readData() return type from uint32_t to int32_t:
    > 0: bytes written (success)
    0: transient condition, caller should retry (timing or entropy)
    < 0: fatal error code from infnoise_error_t
    Add last_error field to infnoise_context for detailed diagnostics.
    Existing errorFlag and message fields preserved for backward compat.
    Fix existing bug: USB write failure in readData set errorFlag but did
    not return, allowing execution to fall through to the USB read.
    Update all callers: CLI (infnoise.c), example-simple.c, example-complex.c.
    Callers now che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
    [libinfnoise_private.h]
2026-05-16 Fixes for Mac build.
    [healthcheck.c]

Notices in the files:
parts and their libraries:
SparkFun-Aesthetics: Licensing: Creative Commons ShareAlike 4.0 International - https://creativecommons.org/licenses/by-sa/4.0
